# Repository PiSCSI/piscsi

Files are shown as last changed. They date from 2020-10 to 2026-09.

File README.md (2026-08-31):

# What is PiSCSI?









PiSCSI is a virtual SCSI device emulator that runs on a Raspberry Pi through the [PiSCSI hat](https://github.com/PiSCSI/piscsi/wiki/Hardware-Versions).
The software runs in userspace, and can emulate several SCSI devices at one time.
There is a control interface to attach / detach drives during runtime, as well as insert and eject removable media.

This project aims to be compliant with the SCSI specification and usable with any standards compliant SCSI controller (see [compatibility list](https://github.com/PiSCSI/piscsi/wiki/Compatibility)).
A handful of PiSCSI features were written specifically for vintage Macintosh and Atari computers and may depend on non-free device drivers on the host machine.

PiSCSI is a fork of [RaSCSI](https://github.com/RaSCSI/RaSCSI) and maintains compatibility with any RaSCSI hat.

Please check out the full story with much more detail on the [wiki](https://github.com/PiSCSI/piscsi/wiki)!

Browse the generated [PiSCSI command documentation](https://piscsi.github.io/piscsi/).

## How do I contribute?

PiSCSI is using a variant of the Gitflow Workflow. A quick overview:

- The *main* branch should always reflect the contents of the last stable release
- The *develop* branch should contain the latest tested & approved updates. Pull requests should be used to merge changes into develop.
- The rest of the feature branches are for developing new features
- A tag will be created for each "release". The releases will be named \<year\>.\<month\>.\<release number\> where the release number is incremented for each subsequent release tagged in the same calendar month. The first release of the month of January 2021 is called "21.01.01", the second one in the same month "21.01.02" and so on.

Note that the leading zeroes in the month and release number are used only in the git tags. The equivalent version number in the software is 21.1.1, 21.1.2, etc.

When you are ready to contribute code to PiSCSI, follow the [GitHub Forking and Pull Request workflow](https://docs.github.com/en/get-started/exploring-projects-on-github/contributing-to-a-project) to create your own fork where you can make changes, and then contribute it back to the project. Please remember to always make Pull Requests against the *develop* branch.

If you want to add a new translation, or improve upon an existing one, please follow the [Web Interface localization instructions](go/piscsi-web/README.md#updating-localizations). Once the translation is complete, please use the same workflow as above to contribute it to the project.

## GitHub Sponsors

Thank you to all of the GitHub sponsors who support the development community!

Extra special thank you to the Gold level sponsors!

- [@mikelord68](https://github.com/mikelord68)
- [@SamplerSpa-dev](https://github.com/SamplerSpa-de)

Special thank you to the Silver level sponsors!

- [@stinkerton18](https://github.com/stinkerton18)
- [@hsiboy](https://github.com/hsiboy)
- [@pendleton115](https://github.com/pendleton115)
- [@Teufelhunden-0311](https://github.com/Teufelhunden-0311)
- Private sponsor ;]

Thank you to Lin van der Slikke for the red panda logo design!

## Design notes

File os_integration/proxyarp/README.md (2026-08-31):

# PiSCSI NetworkManager profiles

PiSCSI supports two explicitly selected network-adapter topologies on Raspberry
Pi OS Trixie and Forky with NetworkManager. DaynaPort and Host Bridge use the
same host-side profiles. Installing the PiSCSI package only installs inert
templates, services, and `/etc/piscsi/network.conf`; it never creates a bridge,
changes an active connection, starts proxy-ARP, or changes firewall state.

The required `parprouted` and `dhcp-helper` packages are suggested rather than
installed automatically. This prevents `dhcp-helper`'s generic service from
binding DHCP on an existing host interface before the user selects proxy-ARP.

## Wired bridge

Bridge mode is the protocol-complete host-side choice: it supports DHCP,
AppleTalk, multicast, and non-IP Ethernet protocols. NetworkManager must own
the bridge, the physical Ethernet port, and the bridge address. PiSCSI owns
only the ephemeral `piscsi0` TAP membership while a network adapter is
attached. DaynaPort can use that complete Ethernet service; the Host Bridge
driver accepts only its own unicast frames and Ethernet broadcasts.

From a local console, preview and apply the named profile with:

```sh
sudo piscsi-network-profile --dry-run apply bridge eth0
sudo piscsi-network-profile --console-acknowledge apply bridge eth0
```

The command prints every change, refuses to run without NetworkManager, and
creates only the named `PiSCSI wired bridge` and `PiSCSI wired bridge port`
connections. `--console-acknowledge` is explicit approval and skips the
otherwise required local-terminal `APPLY` prompt. It can be removed with
`sudo piscsi-network-profile --console-acknowledge remove bridge`.

For manual configuration, the package provides inert keyfile templates in
`/usr/share/piscsi/network/`. Substitute unique UUIDs, the physical NIC, and
the physical Ethernet MAC in the templates, copy them to
`/etc/NetworkManager/system-connections/` with mode `0600`, then reload
NetworkManager. The bridge MAC must remain distinct from the emulated client
MAC on `piscsi0`. The equivalent commands are:

```sh
ethernet_mac=$(cat /sys/class/net/eth0/address)
nmcli connection add type bridge ifname piscsi_bridge con-name 'PiSCSI wired bridge' ipv4.method auto ipv6.method auto bridge.stp no 802-3-ethernet.cloned-mac-address "$ethernet_mac"
nmcli connection add type ethernet ifname eth0 master piscsi_bridge
nmcli connection up 'PiSCSI wired bridge'
```

Replace `eth0` with the selected physical Ethernet interface. Verify that the
bridge owns DHCP and the selected Ethernet MAC, and that the physical port has
no independent IP address before attaching a PiSCSI network adapter with
`mode=bridge:interface=piscsi_bridge`.

## Wi-Fi proxy ARP

Proxy-ARP exposes a PiSCSI network-adapter client directly on the Wi-Fi IPv4
LAN. It supports IPv4 unicast and DHCP only. It does not provide IPv6,
AppleTalk, multicast, mDNS reflection, or general Ethernet bridging. The Host
Bridge driver additionally accepts only its own unicast frames and Ethernet
broadcasts, regardless of the selected profile.

Before selecting this profile, remove any legacy PiSCSI NAT/firewall rules
manually. The package and profile command never remove, flush, or rewrite
iptables/nftables state. Keep a local console or another recovery path: Wi-Fi
proxy-ARP cannot replace a broken Wi-Fi association and is not a transparent
Ethernet bridge.

Install the suggested dependencies, then preview and apply the profile from a
local console:

```sh
sudo apt install parprouted dhcp-helper
sudo piscsi-network-profile --dry-run apply proxyarp wlan0
sudo piscsi-network-profile --console-acknowledge apply proxyarp wlan0
```

Replace `wlan0` with the NetworkManager-managed Wi-Fi interface holding the
Pi's global IPv4 lease. The command writes only
`/etc/piscsi/network.conf`, reloads PiSCSI runtime configuration, and disables
the generic `dhcp-helper.service` to avoid its UDP/67 conflict. To remove the
PiSCSI selection, use
`sudo piscsi-network-profile --console-acknowledge remove proxyarp`.
`PISCSI_PROXYARP_PROMISC=true` is a compatibility option; PiSCSI records and
restores the flag only if it enabled promiscuous mode itself.

The udev rule starts `piscsi-proxyarp.service` only after PiSCSI creates
`piscsi0`; it then starts the PiSCSI-owned DHCP relay. The relay conflicts with
the generic `dhcp-helper.service` to prevent UDP/67 contention. A NetworkManager
dispatcher restarts both PiSCSI services after the selected uplink reconnects
or receives a changed DHCP lease.

Verify an attachment with:

```sh
ip -br link show piscsi0
ip -4 addr show dev piscsi0
systemctl status piscsi-proxyarp piscsi-dhcp-relay
journalctl -u piscsi-proxyarp -u piscsi-dhcp-relay -b
```

On detach, PiSCSI removes only the exact `/32` it added to `piscsi0`, stops
only PiSCSI-owned processes, and restores promiscuous mode only when it had
changed it. It does not flush addresses, routes, or firewall state.

## Network-adapter attachment

Always submit a complete mode/interface pair. For example:

```sh
scsictl -i 6 -c attach -t scdp -f 'mode=bridge:interface=piscsi_bridge'
scsictl -i 6 -c attach -t scdp -f 'mode=proxyarp:interface=wlan0'
scsictl -i 5 -c attach -t scbr -f 'mode=bridge:interface=piscsi_bridge'
scsictl -i 5 -c attach -t scbr -f 'mode=proxyarp:interface=wlan0'
```

Do not use the retired `inet` parameter or a comma-separated interface list.
They describe the obsolete NAT/implicit-bridge path and are rejected.

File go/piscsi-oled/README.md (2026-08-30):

# PiSCSI OLED monitor

`piscsi-oled` is the standalone Go status monitor for 128×32 and 128×64
SSD1306 I2C displays. It shares the PiSCSI daemon client and protobuf bindings
with piscsi-web and piscsi-ctrlboard.

## I2C prerequisites

On Raspberry Pi OS, install supporting tools and enable I2C:

```sh
sudo apt-get update
sudo apt-get install --no-install-recommends --assume-yes \
  i2c-tools raspi-config
sudo raspi-config nonint do_i2c 0
```

Reboot if I2C was newly enabled. The display is normally available as
`/dev/i2c-1`; use `i2cdetect -y 1` to confirm the bus and its address (the
default is `0x3c`).

## Build and run

From the shared Go module root:

```sh
cd go
go build -o piscsi-oled ./cmd/piscsi-oled
./piscsi-oled --rotation=180 --height=64
```

Print the PiSCSI project version and copyright information without accessing
the display or daemon:

```sh
./piscsi-oled -v
```

The defaults preserve the previous monitor behavior: a 180-degree, 128×32
display at `/dev/i2c-1`, address `0x3c`, polling `localhost:6868` every 1000
milliseconds. Useful flags are:

- `--rotation=0|180`
- `--height=32|64`
- `--refresh_interval=1000`
- `--horizontal_scroll_step=6` (parameter pixels moved per screen refresh; `0` pauses scrolling). SCSI ID and device type remain fixed while the parameter field scrolls. Each scroll cycle holds its starting position for three frames, moves to the end, holds that final position for one additional frame, then restarts at the beginning.
- `--password=TOKEN`
- `--host=localhost` and `--port=6868`
- `--i2c-device=/dev/i2c-1` and `--i2c-address=0x3c`
- `--screensaver=off|ip|blank`
- `--screensaver-idle-timeout=5m` and `--screensaver-move-interval=30s`

### Screensavers

The optional `ip` screensaver keeps the network-status line visible but moves
it to a different text row periodically. The `blank` screensaver clears the
entire panel. Both activate only after the PiSCSI status has not changed for
the configured idle period; device, authentication, or network-status changes
immediately restore the normal display. Polling continues while a screensaver
is active.

```sh
./piscsi-oled --screensaver=ip --screensaver-idle-timeout=5m \
  --screensaver-move-interval=30s

./piscsi-oled --screensaver=blank --screensaver-idle-timeout=5m
```

The default `--screensaver=off` preserves existing behavior. The duration flags
accept Go durations such as `30s`, `5m`, and `1h`.

Run a physical-display diagnostic without connecting to the PiSCSI daemon:

```sh
./piscsi-oled --height=32 --rotation=180 --diagnostic
```

It shows the embedded startup and shutdown splash screens, clears the panel,
and exits. Test this on both display heights and rotations after installing the
binary; standard CI cannot exercise I2C hardware.

## Service

The `piscsi-oled` Debian package installs and manages the
[`piscsi-oled.service`](../../os_integration/systemd/piscsi-oled.service)
unit. It runs with a dynamic unprivileged user and the `i2c` supplementary
group; ensure the I2C device grants group access. On `SIGINT` or `SIGTERM`,
the monitor shows the shutdown splash, blanks the panel after 700 ms, and
exits.

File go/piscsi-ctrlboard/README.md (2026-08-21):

# PiSCSI Control Board client

`piscsi-ctrlboard` is the Go client for the PiSCSI Control Board. It reads the
rotary encoder and buttons through the PCA9554 I2C expander, presents the menu
on a 128x64 SSD1306 I2C display, and sends PiSCSI daemon commands for SCSI-ID
management, image attach/eject, profiles, and system actions. The input path
is kept separate from menu, network, and display work so that hardware events
remain responsive.

It is intended to run on a Raspberry Pi with the Control Board attached. By
default it uses `/dev/i2c-1`, PCA9554 address `0x3f`, SSD1306 address `0x3c`,
and BCM GPIO 9 for the expander interrupt. The PiSCSI daemon is expected at
`localhost:6868`.

The PiSCSI Control Board hardware and original Python client were created by
Benjamin Zeiss, and the Go client is a rewrite of that software.

## I2C and GPIO prerequisites

Enable I2C on Raspberry Pi OS and verify that the board devices are visible:

```sh
sudo apt-get update
sudo apt-get install --no-install-recommends --assume-yes i2c-tools raspi-config
sudo raspi-config nonint do_i2c 0
i2cdetect -y 1
```

Reboot if I2C was newly enabled. The usual addresses are `0x3c` for the
display and `0x3f` for the PCA9554. The process also needs access to
`/dev/gpiochip0`; run it with the appropriate device permissions or through
the service manager.

## Build and run

From the shared Go module root, build the native binary and run it on the Pi:

```sh
cd go
go build -o piscsi-ctrlboard ./cmd/piscsi-ctrlboard
./piscsi-ctrlboard
```

Print the PiSCSI project version and copyright information without accessing
the Control Board hardware or daemon:

```sh
./piscsi-ctrlboard -v
```

The Makefile offers equivalent build targets, including cross-compilation for
Raspberry Pi targets:

```sh
cd go
make build-ctrlboard
make build-ctrlboard-linux-arm64
make build-ctrlboard-linux-armv7
```

Use `--help` to list all options. Common overrides include `--host` and
`--port` for the daemon, `--password` for a daemon token, `--rotation=180` for
an inverted display, and `--transitions` to animate submenu navigation. Set
`--display=false` to disable SSD1306 rendering; the Control Board PCA9554 and
GPIO interrupt are still required.

```sh
./piscsi-ctrlboard --host=piscsi.local --port=6868 --rotation=180
./piscsi-ctrlboard --diagnostic
```

Diagnostic mode logs PCA9554 snapshots, decoded input events, queue drops, and
latency counters. It is useful when verifying encoder direction, button
debounce, I2C addresses, or the GPIO interrupt connection.

## Service

The `piscsi-ctrlboard` Debian package installs
[`piscsi-ctrlboard.service`](../../os_integration/systemd/piscsi-ctrlboard.service).
Enable it after installing the package:

```sh
sudo systemctl enable --now piscsi-ctrlboard
```

Use a systemd drop-in to pass non-default hardware addresses, daemon
connection details, or display options.

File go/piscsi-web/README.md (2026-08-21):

# PiSCSI Web Interface (Go)

Go implementation of the PiSCSI web interface, providing a browser-based control panel for the PiSCSI SCSI emulator.

## Components

### Web Interface (`piscsi-web`)

HTTP server providing:

- Immediate access without a login page
- Device management (attach/detach SCSI devices)
- File operations (upload/download/manage disk images)
- System administration
- Server-rendered HTML forms

**Architecture:**

- **Form-post centric**: POST-Redirect-GET pattern with flash messages
- **Minimal JavaScript**: Designed for retro computers (only confirmations/prompts)
- **Template-driven**: Server-side HTML rendering via Go templates

The web interface does not expose a general-purpose JSON API and does not
preserve the former Python web client's `Accept: application/json` response
contract. Form and page routes always use HTML responses or redirects. The
`/healthcheck` endpoint deliberately returns a small JSON response for service
monitoring; downloads and static resources use their corresponding media
types. Any future automation API should be introduced as a separately
documented and versioned interface.

### Mock PiSCSI Daemon (`mock-piscsi`)

Minimal gRPC server simulating the PiSCSI daemon for development/testing without hardware.

## Building

### Baseline Build Environment

For normal PiSCSI installations, use a published PiSCSI binary; Go is needed
only when building from source.

The source build is distribution-independent. It requires:

- Go 1.25 or newer, or Go 1.21 or newer as a bootstrap toolchain
- Git, Make, CA certificates, and OpenSSL
- Network access to download Go modules, unless the module cache is already
  populated

The module requires Go 1.25 and selects a patched Go release with the
`toolchain` directive in `go.mod`. An operating system whose packaged Go
version is older than 1.25 can use Go's automatic toolchain selection instead
of replacing its system compiler. This applies to any distribution with Go
1.21 through 1.24, including Raspberry Pi OS based on Debian Trixie with its
Go 1.24 package.

Go versions older than 1.21 cannot perform automatic toolchain selection.
On such systems, install a current Go toolchain directly, use the release
container, or install a published PiSCSI binary.

The build generates Go bindings from the canonical schema in
`../../proto/piscsi_interface.proto`. It requires the Protocol Buffers compiler
and the Go protobuf generator.

On Debian-family systems, install the bootstrap compiler and native build
dependencies with:

```shell
sudo apt-get update
sudo apt-get install --yes ca-certificates git golang-go make openssl protobuf-compiler
go install google.golang.org/protobuf/cmd/protoc-gen-go@v1.36.11
export PATH="$(go env GOPATH)/bin:$PATH"
```

Install the equivalent packages through the system package manager on other
operating systems.

### Build Commands

**Web interface:**

From `go/piscsi-web`, select the toolchain, verify the source, and build the
application with:

```shell
GOTOOLCHAIN=auto go version
GOTOOLCHAIN=auto go mod download
make test
go vet -tags nomsgpack ./...
make build
```

`make test` is portable to 32-bit ARM and Raspberry Pi kernels that cannot run
Go's race detector. On a supported development host, run `make test-race` to
include race detection.

Run these commands from the module directory so the `go` command sees the
version requirements in `go.mod`. Confirm that the first command reports the
patched toolchain selected by `go.mod`, rather than an older bootstrap
toolchain or an unpatched Go 1.25.0 toolchain.

Automatic toolchain selection requires network access to a Go module proxy and
the checksum database. For a reproducible or offline package build, install the
exact Go toolchain version used by CI in advance, or build in the release
container. Keep the `toolchain` directive in `go.mod` synchronized with
`GO_VERSION` in `.github/workflows/go-web.yml`.

PiSCSI does not expose Gin's optional MessagePack binding or renderer. Supported
builds therefore use Gin's `nomsgpack` build tag, which avoids compiling the
memory-intensive `ugorji/codec` dependency. This is especially important when
building natively on a Raspberry Pi 3.

On a low-memory system, also limit Go to one package build at a time:

```shell
make build GOBUILD='go build -p=1'
```

If native tests also encounter memory pressure, use the same setting:

```shell
make test GOTEST='go test -p=1'
```

Static builds are also available:

```shell
make build-linux-arm64-static
make build-linux-armv7-static
```

**Mock daemon:**

```shell
make mock
```

**Regenerate protobuf bindings:**

```shell
make proto
```

### Custom build-time data-directory defaults

The `BASE_DIR`, `SHARED_DIR`, `CONFIG_DIR`, `DRIVER_DIR`, and
`DRIVE_PROPERTIES_FILE` environment
variables override the application's defaults at runtime.
When building a binary for a legacy installation where data dirs are under `/home/pi`,
the fallback defaults can instead be selected with Makefile variables:

```shell
make build \
  DEFAULT_BASE_DIR=/home/pi/images \
  DEFAULT_SHARED_DIR=/home/pi/shared \
  DEFAULT_CONFIG_DIR=/home/pi/.config/piscsi \
  DEFAULT_DATA_DIR=/home/pi \
  DEFAULT_DRIVE_PROPERTIES_FILE=/home/pi/drive_properties.json \
  DEFAULT_SESSION_KEY_FILE=/home/pi/.config/piscsi/session.key
```

The resulting binary uses these directories only when the corresponding
environment variable is unset. `DEFAULT_SESSION_KEY_FILE` is used only when
`SESSION_KEY_FILE` is unset. `DEFAULT_DRIVE_PROPERTIES_FILE` is used only when
`DRIVE_PROPERTIES_FILE` is unset. `DEFAULT_DATA_DIR` sets the support-data root;
the default driver directory is its `mac-hard-disk-drivers` subdirectory.

The packaged installation stores root-owned, read-only support data below
`/var/lib/piscsi/data`. The Macintosh driver images occupy its
`mac-hard-disk-drivers` subdirectory, leaving the parent directory available
for future PiSCSI support data.

## Installing

Run the installer from `go/piscsi-web` after building the application. On
x86_64, the native build name can be installed directly:

```shell
make build
sudo make install
```

On Raspberry Pi, name the binary for the target architecture because the
installer uses the architecture suffix to select it:

```shell
# 64-bit Raspberry Pi OS (ARM64)
make build-linux-arm64
sudo make install
```

```shell
# 32-bit Raspberry Pi OS (ARMv7)
make build-linux-armv7
sudo make install
```

The installer copies the selected web binary and assets to `/opt/piscsi/web`,
installs the systemd unit, creates the service account and data directories,
creates an empty default environment file, provisions the browser-session key,
and enables the web service.

### Optional Macintosh driver injection

Macintosh driver injection when creating HFS images is optional. The installer
does not provide driver images. Place regular `.bin` or `.img` driver files in
the default driver directory; the web interface lists them as HFS formatting
options:

```shell
sudo install -d -o root -g root -m 0755 /var/lib/piscsi/data/mac-hard-disk-drivers
sudo install -o root -g root -m 0644 /path/to/driver.bin /path/to/driver.img \
  /var/lib/piscsi/data/mac-hard-disk-drivers/
```

Files whose names start with `miniscsi` are created with an `Apple_Driver43`
partition and MiniSCSI-specific boot metadata. Other driver files use the legacy
16 KiB `Apple_Driver` format.

Alternatively, set `DRIVER_DIR` to an existing, readable directory containing
those files. Without the driver images, the web service remains available but
the corresponding image-format options cannot be used.

Archive inspection and extraction use the `lsar` and `unar` commands from the
Debian `unar` package. `easyinstall.sh` installs this package automatically.
For a standalone Go installation, install it before starting the service:

```shell
sudo apt-get install --yes unar
```

Verify the installation with:

```shell
sudo systemctl status piscsi-web
sudo journalctl -u piscsi-web -f
```

### Migrating from the Python web interface

The Python web interface stored disk images in `~/images`, shared files in
`~/shared_files`, and saved configurations and image-property files in
`~/.config/piscsi`. After installing the Go web interface, stop the web
service and run:

```shell
sudo systemctl stop piscsi-web
sudo make migrate-data
sudo systemctl start piscsi-web
```

The migration copies these files to the default directories under
`/var/lib/piscsi`, applies the ownership and permissions required by the
`piscsi-web` service, and imports a legacy backend authentication token into
the protected `/etc/piscsi-web/piscsi-web.env` file. Existing destination
files are preserved, and the source files are not removed. It also copies
existing Macintosh driver images from `~/mac-hard-disk-drivers` to
`/var/lib/piscsi/data/mac-hard-disk-drivers`. Use
`./scripts/migrate-data.sh --dry-run` to preview the migration or
`--source-home PATH` when the legacy installation did not use `/home/pi`.

Legacy RaSCSI 21.10 configuration files with a JSON list at the top level
cannot be converted by the migration script. Load and re-save them with the
Python web interface before switching. Current object-format JSON files retain
their schema, with absolute paths under the legacy image directory converted
to portable relative image paths.

## Running

### Development Mode

```shell
# Terminal 1: Start mock daemon
./mock-piscsi

# Terminal 2: Start web interface
SESSION_KEY="$(openssl rand -base64 32)" \
BASE_DIR=/absolute/path/to/images \
SHARED_DIR=/absolute/path/to/shared \
CONFIG_DIR=/absolute/path/to/config \
DRIVER_DIR=/absolute/path/to/mac-hard-disk-drivers \
./piscsi-web
```

Access at: <http://localhost:8080>

Create the configured data directories before starting the process. Direct
`SESSION_KEY` use is development-only and creates a new session identity each
time the example is run. To preserve development sessions across restarts,
write `openssl rand -base64 32` to a mode `0600` file once and configure its
absolute path through `SESSION_KEY_FILE`.

### Saved configurations

The Go web interface uses the current object-format JSON configuration with
`version`, `devices`, and `reserved_ids` fields. Reservation memos are not
supported; a `memo` field in an existing object-format file is ignored.
When `default.json` is present in the configured configuration directory, it
is validated and loaded automatically during web-server startup.

The obsolete RaSCSI 21.10 format, which uses a device list at the top level, is
not supported. To migrate one of these files, load it with the Python web
client and save it again. The resulting object-format file can then be loaded
by the Go web interface.

### Production Mode

On a packaged installation, start the web interface through systemd:

```shell
sudo systemctl start piscsi-web
sudo systemctl status piscsi-web
```

The packaged web service runs as the dedicated `piscsi-web` system user with
the `piscsi` group. The interface is usable immediately after loading and does
not authenticate browser users. Keep it restricted to a trusted network.

Do not run `/opt/piscsi/web/piscsi-web` directly as a regular user: the
production session master key is deliberately readable only by root and the
`piscsi` service group.

For development or a manually launched private instance, use a separate
session key and user-writable data directories rather than changing the
permissions of the production key.

Default configuration:

- Server: `0.0.0.0:8080`
- PiSCSI daemon: `localhost:6868`
- Disk images: `/var/lib/piscsi/images`
- Shared files: `/var/lib/piscsi/shared`
- Saved configuration: `/var/lib/piscsi/config`
- Macintosh hard disk drivers: `/var/lib/piscsi/data/mac-hard-disk-drivers`
- Session master key: `/etc/piscsi-web/session.key`
- Protected configuration: `/etc/piscsi-web/piscsi-web.env`

### System Data Permissions

The packaged services are expected to use the following ownership and
permission modes. The optional support-data rows apply only when Macintosh
driver injection has been configured:

| Path | Owner and group | Mode |
| --- | --- | --- |
| `/var/lib/piscsi` | `root:piscsi` | `2770` |
| `/var/lib/piscsi/images` | `root:piscsi` | `2770` |
| `/var/lib/piscsi/shared` | `root:piscsi` | `2770` |
| `/var/lib/piscsi/config` | `piscsi-web:piscsi` | `2770` |
| `/var/lib/piscsi/data` | `root:root` | `0755` |
| `/var/lib/piscsi/data/mac-hard-disk-drivers` | `root:root` | `0755` |
| `/var/lib/piscsi-web` | `piscsi-web:piscsi` | `0700` |
| `/etc/piscsi-web` | `root:piscsi` | `0750` |
| `/etc/piscsi-web/piscsi-web.env` | `root:piscsi` | `0640` |
| `/etc/piscsi-web/session.key` | `root:piscsi` | `0640` |

Mode `2770` sets the setgid bit on shared directories so newly created files
inherit the `piscsi` group. Both services use `UMask=0007`. The configuration
directory and session key permissions must not be relaxed merely to let regular
users launch the production service manually.

### Session-key provisioning and rotation

The installer preserves a valid `/etc/piscsi-web/session.key` byte-for-byte on
upgrade. It generates a new key only when that file does not exist. A malformed
or short existing key stops the installation instead of replacing it.

The new file contains standard base64 that decodes to at least 32 random bytes.
The application derives separate cookie-authentication and cookie-encryption
keys using HKDF-SHA-256; the master key itself is never logged. The cookie
stores per-browser language and theme preferences plus short-lived flash
messages. Signing prevents client-side tampering, while encryption avoids
exposing operational messages and paths to the browser.

Rotate the production key only as a deliberate maintenance action:

```shell
sudo systemctl stop piscsi-web
umask 077
SESSION_KEY_TMP=$(mktemp)
openssl rand -base64 32 > "$SESSION_KEY_TMP"
sudo install -o root -g piscsi -m 0640 \
  "$SESSION_KEY_TMP" /etc/piscsi-web/session.key
rm -f "$SESSION_KEY_TMP"
sudo systemctl start piscsi-web
```

Rotation immediately invalidates every existing browser preference and pending
flash message. Keep a protected backup of the previous key until the restart is
verified if rollback must preserve these cookies.

## Configuration

Environment variables:

- `PISCSI_HOST`: PiSCSI daemon host (default: `localhost`)
- `PISCSI_PORT`: PiSCSI daemon port (default: `6868`)
- `PISCSI_TOKEN`: Token password for an authenticated PiSCSI daemon; the
  equivalent `--password` command-line option overrides it when non-empty
- `SERVER_HOST`: Web server listen host (default: `0.0.0.0`)
- `SERVER_PORT`: Web server port (default: `8080`)
- `BASE_DIR`: Disk image directory (default: `/var/lib/piscsi/images`)
- `SHARED_DIR`: Shared-file directory (default: `/var/lib/piscsi/shared`)
- `CONFIG_DIR`: Saved configuration directory (default: `/var/lib/piscsi/config`)
- `DRIVER_DIR`: Lido and SpeedTools driver-image directory (default:
  `/var/lib/piscsi/data/mac-hard-disk-drivers`)
- `DRIVE_PROPERTIES_FILE`: Drive property presets (default:
  `drive_properties.json`; Debian package: `/etc/piscsi-web/drive_properties.json`)
- `TEMPLATES_DIR`: HTML template directory used only as a development fallback
  (default: `web/templates`; the release binary embeds templates)
- `STATIC_DIR`: Static-asset directory used only as a development fallback
  (default: `web/static`; the release binary embeds static assets)
- `MAX_FILE_SIZE`: Maximum upload size in bytes (default: `4294967296`; maximum:
  `146789695488`, the largest supported drive preset)
- `SESSION_MAX_AGE`: Session lifetime in seconds (default: `86400`)
- `SESSION_KEY_FILE`: Protected base64 master-key file (default:
  `/etc/piscsi-web/session.key`)
- `SESSION_KEY`: Development-only base64 master key used only when
  `SESSION_KEY_FILE` is not configured

`SESSION_KEY_FILE` takes precedence when both secret settings are present,
including when the file setting is explicitly empty or invalid. Production
deployments must use the file. All configured numbers, hosts, paths, and
required directory access are validated before the server is constructed;
malformed values never fall back to defaults.

Startup fails if the session key is missing, malformed, too short, group-writable, or
accessible by other users, if a required directory is unusable, or if the
PiSCSI daemon requires a missing or invalid token.

Because there is no browser authentication, public-internet exposure is
unsupported. Keep the service on a trusted LAN.

## Updating Localizations

The gettext catalogs are stored as uncompiled PO files under
`web/translations/<locale>/LC_MESSAGES/messages.po` and are embedded directly
in the binary. Install GNU gettext (`gettext` on Debian and Homebrew) before
maintaining them.

The Go renderer looks up the final English text produced by the templates and
handlers. From `go/piscsi-web`, extract these messages, regenerate
`messages.pot`, merge the template into every PO file, and validate the
results with:

```shell
./scripts/update-translations.sh
```

The script stages and validates the generated POT and every merged PO file
before replacing any source file. Existing translations are retained when
their message IDs still match. Review new, fuzzy, and obsolete entries after
running it, update their translations, and run the script again before
committing `messages.pot` and the PO files.

## Project Structure

```shell
.
├── cmd/
│   ├── piscsi-web/       # Web server entrypoint
│   └── mock-piscsi/      # Mock daemon entrypoint
├── internal/
│   ├── server/         # HTTP handlers, routing, flash messages
│   ├── piscsi/         # gRPC client for PiSCSI daemon
│   ├── config/         # Configuration management
│   └── driveprops/     # Drive properties database
├── web/
│   ├── templates/      # HTML templates
│   └── static/         # CSS, JS, images
├── drive_properties.json
└── mock-piscsi         # Built mock daemon
```

## Development Notes

- Templates are embedded in the binary via `embed` directives
- Session storage uses gorilla/sessions with cookie-based persistence
- Flash messages require `gob.Register()` for serialization
- `../../proto/piscsi_interface.proto` is the canonical protocol definition.
- Go bindings are generated automatically by Make targets and are not committed.

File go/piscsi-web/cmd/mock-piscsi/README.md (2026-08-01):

# Mock PiSCSI Daemon

A lightweight mock implementation of the PiSCSI daemon for testing the web frontend without physical hardware.

## Quick Start

Build and run the mock daemon:

```shell
# Build the mock daemon
make mock

# Run it (listens on port 6868)
./mock-piscsi
```

In another terminal, start the web interface:

```shell
DISABLE_PAM=true FALLBACK_USER=test FALLBACK_PASSWORD=test ./piscsi-web
```

Then open <http://localhost:8080> in your browser.

## Features

The mock daemon responds to all major PiSCSI operations:

- **VERSION_INFO** - Returns mock version information
- **SERVER_INFO** - Returns full server configuration
- **DEVICES_INFO** - Lists attached devices (initially one mock drive)
- **DEFAULT_IMAGE_FILES_INFO** - Lists available disk images
- **DEVICE_TYPES_INFO** - Returns supported device types
- **LOG_LEVEL_INFO** - Returns log level information
- **NETWORK_INTERFACES_INFO** - Returns network interfaces
- **ATTACH** - Simulates attaching a device
- **DETACH/DETACH_ALL** - Simulates detaching devices

## Customizing Mock Data

All mock responses are generated by functions in `main.go`. To customize:

### Add More Mock Images

Edit `getMockImageFilesInfo()`:

```go
ImageFiles: []*pb.PbImageFile{
    {
        Name:     "my-custom-disk.hda",
        Type:     pb.PbDeviceType_SCHD,
        Size:     21474836480, // 20GB
        ReadOnly: false,
    },
    // Add more images here...
}
```

### Add Mock Attached Devices

Edit `getMockDevicesInfo()`:

```go
Devices: []*pb.PbDevice{
    {
        Id:         1,
        Unit:       0,
        Type:       pb.PbDeviceType_SCCD,  // CD-ROM
        Status:     "ready",
        File:       "system-cd.iso",
        Vendor:     "PiSCSI",
        Product:    "CD-ROM",
        Revision:   "1.0",
        BlockSize:  2048,
        BlockCount: 300000,
    },
    // Add more devices here...
}
```

### Change Version Info

Edit `getMockVersionInfo()`:

```go
return &pb.PbVersionInfo{
    MajorVersion: 25,
    MinorVersion: 0,
    PatchVersion: 1,
    Suffix:       "-custom",
}
```

## Protocol Details

The mock daemon implements the PiSCSI protobuf protocol:

1. Client sends: `RASCSI` (6 bytes) + size (4 bytes, LE) + protobuf message
2. Server responds: size (4 bytes, LE) + protobuf message

All operations are logged to stdout for debugging.

## Tips

- Run with `2>&1 | tee mock.log` to save logs
- The mock daemon doesn't validate requests - it always returns success
- Restart the daemon to reset all state
- You can run multiple instances on different ports by modifying the `Port` constant

## Troubleshooting

**Port already in use:**

```shell
# Find what's using port 6868
lsof -i :6868

# Or kill all piscsi processes
pkill piscsi
pkill mock-piscsi
```

**Web interface can't connect:**

- Make sure the mock daemon is running first
- Check the daemon logs for incoming connections
- Verify the web interface is configured for localhost:6868 (default)

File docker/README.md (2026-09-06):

# Docker Environment for Development and Testing

⚠️ **Important:** The Docker environment is unable to connect to the PiSCSI board and is
intended for development and testing purposes only. To setup PiSCSI on a Raspberry Pi
refer to the [setup instructions](https://github.com/PiSCSI/piscsi/wiki/Setup-Instructions)
on the wiki instead.

## Introduction

This documentation covers developing and testing the Go web UI.

Additions, amendments and contributions for additional workflows are most welcome.

## Getting Started

The easiest way to launch a new environment is to use Docker Compose.

```sh
cd docker
docker compose up
```

Containers will be built and started for the PiSCSI server and the web UI.

The web UI can be accessed at:

* http://localhost:8080

To stop the containers, press *Ctrl + C*, or run `docker compose stop` 
from another terminal.

## Environment Variables

The following environment variables are available when using Docker Compose:

| Environment Variable | Default  |
| --- |---|
| `OS_VERSION` | trixie |
| `WEB_HTTP_PORT` | 8080 |
| `BACKEND_HOST` | backend  |
| `BACKEND_PORT` | 6868 |
| `BACKEND_PASSWORD` | *[None]* |
| `BACKEND_LOG_LEVEL`  | debug |
| `PISCSI_DOCKER_UID`  | 1000 |
| `PISCSI_DOCKER_GID`  | 1000 |

**Examples:**

Run Debian "trixie":

```sh
OS_VERSION=trixie docker compose up
```

The Docker entrypoint generates an ephemeral session key for local development.
Set `SESSION_KEY` yourself if browser sessions must survive a container restart.

Run the Go web-client test suite with:

```sh
docker compose --profile webui-tests run --rm go-test
```

## Volumes

When using Docker Compose the following volumes will be mounted automatically:

| Local Path | Container Path |
| --- | --- |
| docker/volumes/images/  | /var/lib/piscsi/images/  |
| docker/volumes/config/  | /var/lib/piscsi/config/  |

## How To

### Rebuild Containers

You should rebuild the container images after checking out a different version of
PiSCSI or making changes to the Go web client or its runtime dependencies.

```sh
docker compose up --build
```

### Open a Shell on a Running Container

Run the following command, replacing `[CONTAINER]` with `backend` or `web`.

```sh
docker compose exec [CONTAINER] bash
```

### Setup Live Editing for the Web UI

Use a `docker-compose.override.yml` to mount the local `go` directory into the
build workspace used by the `go-test` service.

The web binary embeds templates and static assets, so rebuild and restart the
`web` service after editing Go web-client files.

**Example:**

```yaml
services:
  go-test:
    volumes:
      - ../go:/src/go:delegated
```

### Connect the Web UI to a Real PiSCSI

This can be useful for testing, but there are some caveats, e.g. the PiSCSI and the
web UI will be accessing separate `images` directories.

```sh
BACKEND_HOST=foo BACKEND_PASSWORD=bar docker compose up
```

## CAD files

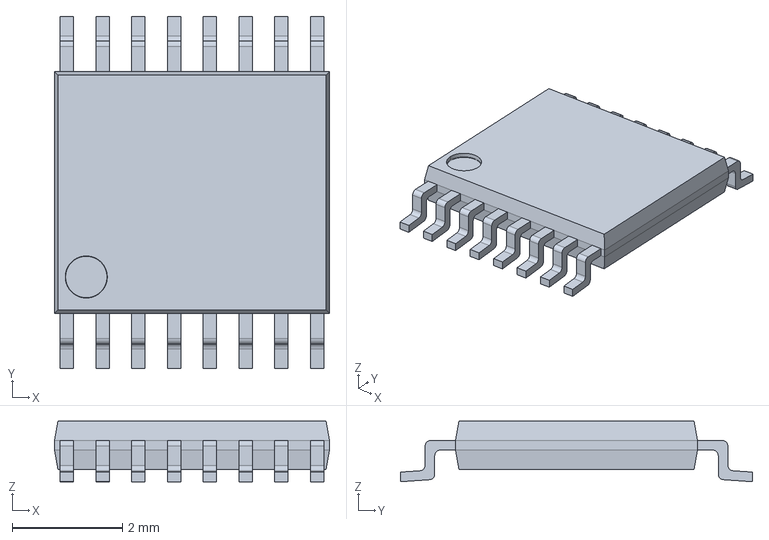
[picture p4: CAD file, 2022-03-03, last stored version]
hw/ctrl_board_v1p5/PCA9554APW_118/PCA9554APW_118.step
5.00 x 6.41 x 1.10 mm

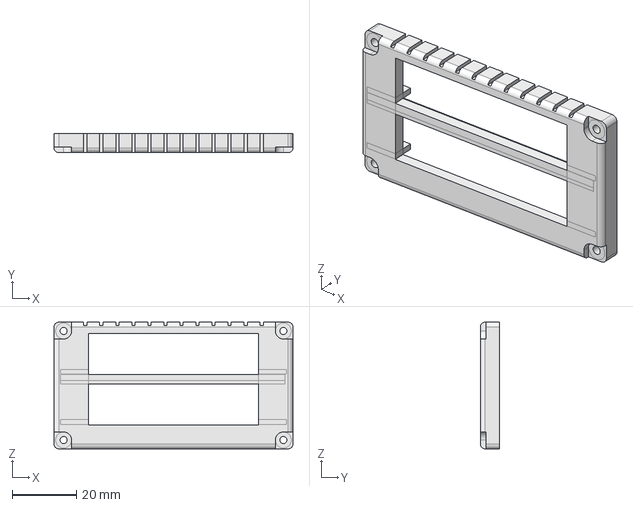
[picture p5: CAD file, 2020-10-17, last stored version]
hw/IIciCase/IIciCase.FCStd
74.5 x 6.00 x 39.5 mm

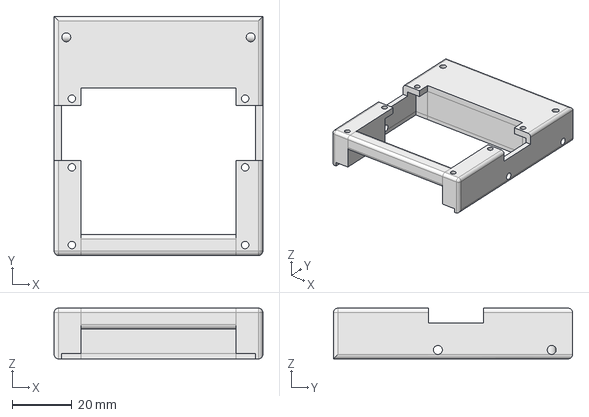
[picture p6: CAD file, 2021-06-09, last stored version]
hw/pb_bracket/powerbook_bracket.step
69.8 x 80.0 x 17.0 mm

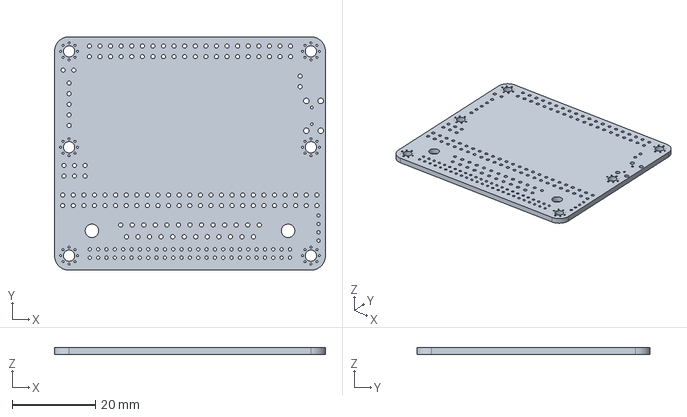
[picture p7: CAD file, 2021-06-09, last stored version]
hw/rascsi_2p4/rascsi_2p4.step
65.0 x 56.0 x 1.60 mm

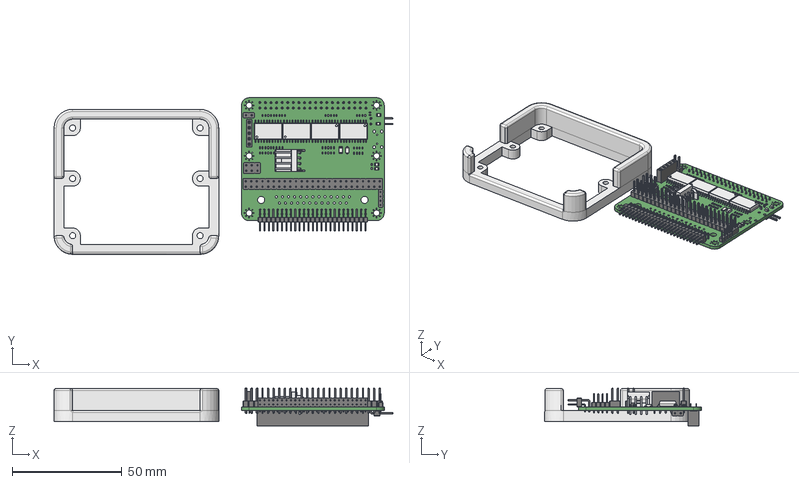
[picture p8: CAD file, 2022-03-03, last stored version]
hw/rascsi_pogo_holder/rascsi_pogo_holder.FCStd
154.3 x 71.3 x 17.2 mm
RaSCSI Holder

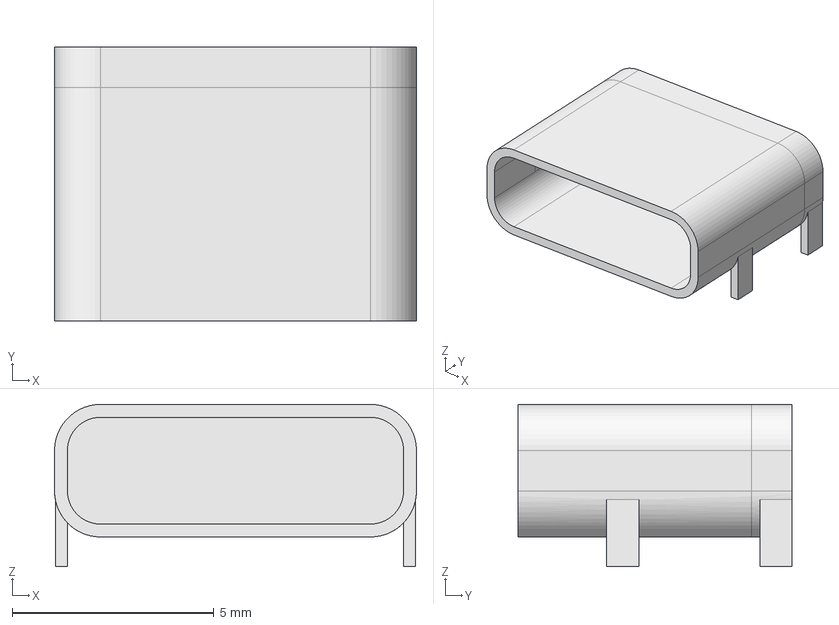
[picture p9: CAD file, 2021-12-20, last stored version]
hw/rascsi_zero_1p0/TYPE-C-31-M-17/type-c-31-m-17-Body.step
8.98 x 6.80 x 4.03 mm

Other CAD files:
hw/rascsi_2p5/rascsi_2p5.step
hw/rascsi_zero_1p0/TYPE-C-31-M-17/type-c-31-m-17.FCStd
hw/pb_bracket/powerbook_bracket.FCStd
hw/pb_bracket/powerbook_bracket.stl
hw/rascsi_pogo_holder/rascsi_pogo_holder.stl

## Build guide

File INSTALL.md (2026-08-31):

# Installing PiSCSI

The recommended way to install PiSCSI is via the binary deb packages.
Find the latest release on the [GitHub releases page](https://github.com/PiSCSI/piscsi/releases) and download the `piscsi_*.deb` file for your Raspberry Pi architecture.

If you want the Web interface, download the `piscsi-web_*.deb` file as well.
If your Raspberry Pi has an OLED screen, download the `piscsi-oled_*.deb` file, and if you have a PiSCSI Control Board, download the `piscsi-ctrlboard_*.deb` file.

## Runtime dependencies

Use apt to install the packages and their dependencies, for example the mandatory runtime dependencies for the _piscsi_ daemon:

```sh
sudo apt update
sudo apt install libprotobuf-dev libspdlog-dev libpcap-dev
```

The _piscsi_ daemon requires the following packages to be installed on the system:

- `libprotobuf-dev` for the protobuf runtime library
- `libspdlog-dev` for the spdlog runtime library
- `libpcap-dev` for the pcap runtime library

Note that the _-dev_ packages are not strictly required at runtime, but they are the easiest way to install the libraries on Debian-based systems, since
they are named consistently regardless of the Raspberry Pi architecture. The _-dev_ packages are also required to build PiSCSI from source.

In addition, these optional packages enables additional functionality:

- `dhcp-helper` for proxy ARP support
- `parprouted` for proxy ARP support
- `rsyslog` for logging

The _piscsi-web_ package has the following optional runtime dependencies:

- `genisoimage` for creating ISO images
- `unar` for extracting compressed archives
- `dosfstools` for creating FAT filesystems
- `hfdisk` for creating HFS partition tables
- `hfsutils` for creating HFS filesystems
- `groff` for displaying man pages
- `man2html` for converting man pages to HTML
- `disktype` for identifying disk image types

The _piscsi-oled_ and _piscsi-ctrlboard_ packages have the following optional runtime dependency:

- `i2c-tools` for configuring and testing I2C devices

## Installing the packages

Use `dpkg` to install the downloaded packages. For example, if you downloaded the `piscsi_*.deb` and `piscsi-web_*.deb` files to your home directory:

```sh
sudo dpkg -i ~/piscsi_*.deb ~/piscsi-web_*.deb
```

In most cases, dpkg will report missing dependencies. Use `apt` to install them.

## Build from source

This guide builds the C++ PiSCSI daemon and command-line tools from a source checkout.
Note that building the C++ code directly on Raspberry Pi hardware can be very slow.
Cross-compiling on a more powerful host is recommended.

Building from source is most useful for development, testing,
or trying an unreleased change. PiSCSI is developed and tested primarily on
recent Raspberry Pi OS releases.

The C++ code and tests can be built on most Unix-like systems,
but the GPIO hardware interface is only available on a Raspberry Pi with a
PiSCSI hat.

## Build prerequisites

On Raspberry Pi OS, install the PiSCSI C++ build dependencies with:

```sh
sudo apt update
sudo apt install --yes \
  build-essential ca-certificates git protobuf-compiler rsyslog \
  clang libgmock-dev libpcap-dev libprotobuf-dev libspdlog-dev
```

`libgmock-dev` supplies the unit-test dependency. You may omit it when you do
not intend to build or run tests.

For the Meson build system, also install Meson and Ninja:

```sh
sudo apt install --yes meson ninja-build
```

Clone the repository:

```sh
git clone https://github.com/PiSCSI/piscsi.git
cd piscsi
```

The web interface and the optional OLED/control-board programs are built with
Go. Start with the [web interface README](go/piscsi-web/README.md); the OLED
and control-board directories each have their own README as well.

## Build with Meson

Meson is configured from the repository root. A separate build directory keeps
generated files out of the checkout.

```sh
meson setup build
meson compile -C build
```

The default target set builds `piscsi`, `scsictl`, `scsimon`, `scsiloop`,
`scsidump`, and the unit tests. `scsiloop` requires Linux on Raspberry Pi GPIO
hardware.

To select targets explicitly, pass a Meson array option:

```sh
meson setup build -Dtarget=piscsi,scsictl
meson compile -C build
```

Run unit tests when the Google Test/Mock packages are installed:

```sh
meson test -C build
```

Install the Meson-built binaries and installed data with:

```sh
sudo meson install -C build
```

By default this installs executable and manual-page files under `/usr/local`,
along with the other data declared by the Meson project. Use `--prefix` to
change the installation root. You may need to manually adjust the systemd
unit files to match the prefix.

## Build with Make

The legacy Makefile is run from `cpp/`. It compiles C++ sources there and
writes binaries to `cpp/bin/`.

```sh
cd cpp
make -j"$(nproc)" all
```

For a development build with debug symbols and no optimization:

```sh
make -j"$(nproc)" DEBUG=1 all
```

Run the C++ unit tests:

```sh
make -j"$(nproc)" test
```

The Makefile accepts `CROSS_COMPILE`, for example `CROSS_COMPILE=arm-linux-gnueabihf-`, and
`DEFAULT_IMAGE_FOLDER` to change the compiled default image directory.

Install the Make-built development files with:

```sh
sudo make install
```

After a Makefile installation, reload logging and enable/start the service as
needed:

```sh
sudo systemctl restart rsyslog
sudo systemctl enable --now piscsi
sudo systemctl status piscsi
```

The daemon log is written to `/var/log/piscsi.log` when the supplied rsyslog
configuration is active.

## Cleaning and rebuilding

For a clean Makefile build:

```sh
cd cpp
make clean
```

For Meson, remove the build directory and configure it again:

```sh
rm -rf build
meson setup build
```

The two build systems can be used in parallel, but they do not share build artifacts.

For system setup and SCSI hardware guidance, see the
[PiSCSI Setup Instructions](https://github.com/PiSCSI/piscsi/wiki/Setup-Instructions).

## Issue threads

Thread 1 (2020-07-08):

CD-ROM Emulation doesn't work with stock Apple drivers

akuker, 2020-07-08:
The "stock" version of Apple's CD-ROM driver for MacOS 8.x (and probably all versions of "classic" Mac OSs) does not recognize the emulated CD-ROM of RaSCSI. At startup, the CD-ROM driver will send an unsupported command that is not supported by RaSCSI.

I believe this check was done to make sure that only CD-ROMs with Apple firmware were used.

There are a couple work-arounds:
- Install ResExcellence's CD-ROM driver hack (https://web.archive.org/web/20040404121044/http://www.resexcellence.com/hack_html_99/12-21-98.shtml)
- [Untested] Use a 3rd party CD-ROM driver. The CD driver that was distributed with Toast may be a good one to try.

erichelgeson, 2020-10-12:
FYI https://macintoshgarden.org/apps/cd-sunrise-v22b did not work with rascsi cd emulation

rdmark, 2021-08-17:
For the record, the Toast CD Reader driver from https://macintoshgarden.org/apps/astarte-toast-256 does not work either.  The extension just fails to load when testing on System 7.1 (Pro and P6) as well as Mac OS 7.6.1, even though a RaSCSI CD drive is attached.

rdmark, 2021-08-17:
One observation right now, is that since ResExcellence's hack is the only known (?) solution, and the oldest version of Apple CD-ROM that the hack is proven to work with is 5.4.2, effectively the oldest Mac OS version that can be used right now with RaSCSI CD-ROM is 8.1.
Today I spent a few hours trying to hack earlier Apple CD-ROM drivers without success. I also tried to use 5.4.2 with older system software versions, also without success.

rdmark, 2021-08-18:
I've got some good news:  After some research and testing today, I am glad to announce that I've found two 3rd party drivers that work well with RaSCSI:  RapidCD and CD/DVD Drive TuneUp 2.0.3
See my detailed test results here:  http://shorturl.at/wKNY9

My favorite is RapidCD, since it mounts CDs super fast, also can handle the DOS partitions, and is the only one that works on my stock Mac SE.  It even works on System 6.0.7, which blew me away!

uweseimet, 2021-08-21:
@rdmark It would be helpful to have a log on trace level for those cases where software fails to use the emulated devices.

rdmark, 2021-08-22:
@uweseimet This is an example when attaching an image and the system not being able to read the disk.  Hacked Apple CD ROM 5.3.1, System 7.1.1 on a Mac SE.

[2021-08-22 07:07:51.674] [info] Validating: cmd=ATTACH, id=4, unit=0, type=SCCD, filename='/home/pi/images/71.iso', device name='', params=''
[2021-08-22 07:07:51.676] [info] Executing: cmd=ATTACH, id=4, unit=0, type=SCCD, filename='/home/pi/images/71.iso', device name='', params=''
[2021-08-22 07:07:51.679] [info] Media capacity for image file '/home/pi/images/71.iso': 39067 blocks
[2021-08-22 07:07:51.681] [info] Added new SCCD device, ID: 4 unit: 0
[2021-08-22 07:07:51.810] [info] +----+----+------+-------------------------------------
[2021-08-22 07:07:51.813] [info] | ID | UN | TYPE | DEVICE STATUS
[2021-08-22 07:07:51.816] [info] +----+----+------+-------------------------------------
[2021-08-22 07:07:51.816] [info] |  3 |  0 | SCHD | /home/pi/images/600MB.hda
[2021-08-22 07:07:51.824] [info] |  4 |  0 | SCCD | /home/pi/images/71.iso (WRITEPROTECT)
[2021-08-22 07:07:51.825] [info] +----+----+------+-------------------------------------
[2021-08-22 07:07:52.668] [trace] virtual void SCSIDEV::Selection() Selection Phase ID=4 (with device)
[2021-08-22 07:07:52.668] [trace] virtual void SASIDEV::Command() Command Phase
[2021-08-22 07:07:52.668] [trace] virtual void SCSIDEV::Execute() Execution phase command $00
[2021-08-22 07:07:52.669] [debug] ++++ CMD ++++ virtual void SCSIDEV::Execute() ID 4 received CmdTestUnitReady ($00)
[2021-08-22 07:07:52.669] [trace] void SASIDEV::CmdTestUnitReady() TEST UNIT READY Command
[2021-08-22 07:07:52.669] [trace] Setting status: Sense Key: $06, ASC: $28, ASCQ: $00
[2021-08-22 07:07:52.669] [trace] BOOL Disk::CheckReady() Disk in needs attention
[2021-08-22 07:07:52.669] [trace] virtual void SCSIDEV::Error(ERROR_CODES::sense_key, ERROR_CODES::asc) Sense Key and ASC for subsequent REQUEST SENSE: $00, $00
[2021-08-22 07:07:52.669] [trace] virtual void SCSIDEV::Error(ERROR_CODES::sense_key, ERROR_CODES::asc) Error (to status phase)
[2021-08-22 07:07:52.669] [trace] void SASIDEV::Status() Status Phase $02
[2021-08-22 07:07:52.669] [trace] virtual void SCSIDEV::Send() sending handhake with offset 0, length 1
[2021-08-22 07:07:52.670] [trace] virtual void SCSIDEV::Send() Move to next phase status (8)
[2021-08-22 07:07:52.670] [trace] void SASIDEV::MsgIn() Starting Message in phase
[2021-08-22 07:07:52.670] [trace] void SASIDEV::MsgIn() Transitioning to Send()
[2021-08-22 07:07:52.670] [trace] virtual void SCSIDEV::Send() sending handhake with offset 0, length 1
[2021-08-22 07:07:52.670] [trace] void SASIDEV::MsgIn() Transitioning to Send()
[2021-08-22 07:07:52.670] [trace] virtual void SCSIDEV::Send() Move to next phase msgin (9)
[2021-08-22 07:07:52.670] [trace] virtual void SCSIDEV::BusFree() Bus free phase
[2021-08-22 07:07:52.672] [trace] virtual void SCSIDEV::Selection() Selection Phase ID=4 (with device)
[2021-08-22 07:07:52.672] [trace] virtual void SASIDEV::Command() Command Phase
[2021-08-22 07:07:52.673] [trace] virtual void SCSIDEV::Execute() Execution phase command $03
[2021-08-22 07:07:52.673] [debug] ++++ CMD ++++ virtual void SCSIDEV::Execute() ID 4 received CmdRequestSense ($03)
[2021-08-22 07:07:52.673] [trace] void SASIDEV::CmdRequestSense() REQUEST SENSE Command
[2021-08-22 07:07:52.673] [trace] virtual int Disk::RequestSense(const DWORD*, BYTE*) size of data = 18
[2021-08-22 07:07:52.673] [trace] Setting status: Sense Key: $00, ASC: $00, ASCQ: $00
[2021-08-22 07:07:52.673] [trace] void SASIDEV::CmdRequestSense() Sense Key $06, ASC $28
[2021-08-22 07:07:52.673] [trace] void SASIDEV::DataIn() Going into Data-in Phase
[2021-08-22 07:07:52.673] [trace] virtual void SCSIDEV::Send() sending handhake with offset 0, length 18
[2021-08-22 07:07:52.674] [trace] virtual void SCSIDEV::Send() Move to next phase datain (6)
[2021-08-22 07:07:52.674] [trace] void SASIDEV::Status() Status Phase $00
[2021-08-22 07:07:52.674] [trace] virtual void SCSIDEV::Send() sending handhake with offset 0, length 1
[2021-08-22 07:07:52.674] [trace] virtual void SCSIDEV::Send() Move to next phase status (8)
[2021-08-22 07:07:52.674] [trace] void SASIDEV::MsgIn() Starting Message in phase
[2021-08-22 07:07:52.674] [trace] void SASIDEV::MsgIn() Transitioning to Send()
[2021-08-22 07:07:52.674] [trace] virtual void SCSIDEV::Send() sending handhake with offset 0, length 1
[2021-08-22 07:07:52.675] [trace] void SASIDEV::MsgIn() Transitioning to Send()
[2021-08-22 07:07:52.675] [trace] virtual void SCSIDEV::Send() Move to next phase msgin (9)
[2021-08-22 07:07:52.675] [trace] virtual void SCSIDEV::BusFree() Bus free phase
[2021-08-22 07:07:52.676] [trace] virtual void SCSIDEV::Selection() Selection Phase ID=4 (with device)
[2021-08-22 07:07:52.676] [trace] virtual void SASIDEV::Command() Command Phase
[2021-08-22 07:07:52.677] [trace] virtual void SCSIDEV::Execute() Execution phase command $00
[2021-08-22 07:07:52.677] [debug] ++++ CMD ++++ virtual void SCSIDEV::Execute() ID 4 received CmdTestUnitReady ($00)
[2021-08-22 07:07:52.677] [trace] void SASIDEV::CmdTestUnitReady() TEST UNIT READY Command
[2021-08-22 07:07:52.677] [trace] Setting status: Sense Key: $00, ASC: $00, ASCQ: $00
[2021-08-22 07:07:52.677] [trace] BOOL Disk::CheckReady() Disk is ready!
[2021-08-22 07:07:52.677] [trace] void SASIDEV::Status() Status Phase $00
[2021-08-22 07:07:52.678] [trace] virtual void SCSIDEV::Send() sending handhake with offset 0, length 1
[2021-08-22 07:07:52.678] [trace] virtual void SCSIDEV::Send() Move to next phase status (8)
[2021-08-22 07:07:52.678] [trace] void SASIDEV::MsgIn() Starting Message in phase
[2021-08-22 07:07:52.678] [trace] void SASIDEV::MsgIn() Transitioning to Send()
[2021-08-22 07:07:52.678] [trace] virtual void SCSIDEV::Send() sending handhake with offset 0, length 1
[2021-08-22 07:07:52.678] [trace] void SASIDEV::MsgIn() Transitioning to Send()
[2021-08-22 07:07:52.679] [trace] virtual void SCSIDEV::Send() Move to next phase msgin (9)
[2021-08-22 07:07:52.679] [trace] virtual void SCSIDEV::BusFree() Bus free phase
[2021-08-22 07:07:52.680] [trace] virtual void SCSIDEV::Selection() Selection Phase ID=4 (with device)
[2021-08-22 07:07:52.680] [trace] virtual void SASIDEV::Command() Command Phase
[2021-08-22 07:07:52.681] [trace] virtual void SCSIDEV::Execute() Execution phase command $43
[2021-08-22 07:07:52.681] [debug] ++++ CMD ++++ virtual void SCSIDEV::Execute() ID 4 received CmdReadToc ($43)
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
uweseimet, 2021-08-23:
@rdmark The current uweseimet_develop branch contains additional debug output, which should reveal which code page MODE SELECT wants to change. Would be great if you provided updated logs whenever you have the time for it.

rdmark, 2021-08-23:
@uweseimet Do I need to compile rascsi with debug symbols to get the right level of debug output?

rdmark, 2021-08-23:
@uweseimet trace using b40c6b1 on my Mac SE, System 6.0.7, Apple CD-ROM driver.  Up through booting the system off a non-RaSCSI hard drive, the system complaining that the CD file system can't be read, and me hitting the Eject button.
[cd_trace2.txt](https://github.com/akuker/RASCSI/files/7034796/cd_trace2.txt)

uweseimet, 2021-08-23:
@rdmark Thank you for providing updated logs. At least from the new logs we know now which mode page the driver tries to use:

```
[2021-08-23 21:48:02.151] [debug] virtual bool Disk::Dispatch(SCSIDEV*) received CmdModeSelect ($15)
[2021-08-23 21:48:02.151] [trace] MODE SELECT for unsupported page 21
```

When (and if) somebody starts investigating this issue thsi piece of information might be useful.

akuker, 2021-12-30:
There's also an issue with ModeSense6. When the Mac sends the ModeSense6 command, it specifies a size of 0x14 (20 decimal). This graphic shows that RaSCSI doesn't respond to the ModeSense6 for Page 1 request. It transitions to an error status 2.
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

The current RaSCSI code calculates a response of size 24. This is too big, and I don't think RaSCSI is calculating the response size appropriately. The response size should be 20 bytes (as requested by the Mac).... 4 bytes (for the mode sense data header) + 8 bytes (for the block descriptor) + 8 bytes (for the error recovery parameters).

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

@uweseimet - I'm curious about your opinions on the risk associated with this change.

akuker, 2021-12-30:
Another interesting observation - With the Apple CD drive I was using, I didn't ever see a ModeSelect6 (15h) command in the SCSI data capture. I'm going to do some more data captures from some other drives to make sure this wasn't a fluke.

My wild theory? If the drivers get the data they expect from the Inquiry and/or ModeSense6 commands, it doesn't need to change anything using the ModeSelect command.

uweseimet, 2021-12-30:
@akuker Well, there is no risk if your change is compliant with the SCSI specification. If it is not the change will break a lot. In cases like this it is very important to check against the specification.

einstein95, 2022-06-16:
It appears you've got the wrong response for page 0x30 comparing it to the one in MAME (which does work with stock AppleCD drivers). See https://github.com/mamedev/mame/blob/badecba0e3aa372b75c738a4c53b2a7f8332064e/src/devices/bus/nscsi/cd.cpp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

rdmark, 2022-07-08:
@einstein95 Thanks for the tip! In addition to the MODE SENSE piece here, there seems to be an aspect of masquerading with a particular product string in the MAME solution: https://github.com/mamedev/mame/commit/c58e4b2a3e3624299da8362740c6c24a4c428abf

Closed 2022-09-10.

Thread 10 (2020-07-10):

HW: version 1.5 of RaSCSI has ACT signal miswired

akuker, 2020-07-10:
Version 1.5 of the RaSCSI "68kmla" version has an incorrect connection. Pin 1 should be connected to the "ACT" signal, instead of the PI-ACK signal.

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

Workaround:

Cut the trace of ACT running to pin 1 of U3. Scrape off some solder mask on the side near the via.
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

Solder a jumper wire from the trace to Pin 7 of the Raspberry Pi GPIO header.
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

akuker, 2020-07-10:
Tagged as "won't fix". When the next batch of boards (if ever) are ordered, this should be fixed.

phrax0, 2020-08-15:
With the development of the 1.6 board addressing this issue, we can close #10 now.  Also, thanks for doing the 1.6 board akuker!

akuker, 2020-08-16:
Agreed!

Closed 2020-08-16.

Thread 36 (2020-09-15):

Add ID EEPROM to RaSCSI board

quorten, 2020-09-15:
An ID EEPROM is recommended for Raspberry Pi HATs so that drivers can be automatically loaded when the corresponding HAT is connected, and automatically not loaded when a different HAT is connected.  In the particular case of RaSCSI, it would also facilitate indicating to the software whether the standard or fullspec board is connected and it could adapt accordingly.

quorten, 2020-10-23:
@akuker I'm wondering, which future board revision do you think it would be a good idea to work in the hardware changes to add this?  I'm willing to make the changes to add this to a future board revision, but since the boards you've designed are pretty crammed as-is I'm curious what your thoughts/ideas are.

Another thing, I feel like putting a README in the `hw` directory containing a brief description of each hardware revision and its history would be really helpful.

akuker, 2020-10-25:
I was thinking of starting a "3.0" board sometime in the future.

When I started digging into this a couple months ago, I thought I ran into a problem. It looked like the GPIO header pins for the HAT EEPROM conflicted with some of the pins used for RaSCSI signal lines. I haven't found a definitive specification on how this is supposed to be wired though.

Now that I'm double-checking this tonight, the Ki-CAD "Hat" template shows that the EEPROM data/clock lines go to pins 27/28 of the GPIO connector. These are currently unused in the RaSCSI design, so I don't know what I was thinking before.

The 2.7 version of the board originally had the EEPROM on it. There is an area in the center of the board that is wide open. That used to have the EEPROM on there. (Its probably still in some of the previous revisions in Git) You could also put the eeprom on the bottom of the board.

You are welcome to create a "3.0" version and see if you can get something going!

I like the README idea too. This information is available on the wiki https://github.com/akuker/RASCSI/wiki/Hardware-Versions . But, it'd be nice to at least have a README that points to it. I think I shall do that tonight

akuker, 2020-10-25:
@quorten - I guess I didn't look hard enough for the official documentation - https://github.com/raspberrypi/hats/

The camera flex cutout definitely wont fit without a major redesign. The display flex cutout might be do-able, but not sure its worth it.

quorten, 2020-10-25:
So I've started through the schematics, and I might have spotted a design oversight.

What was the particular problem that the Raspberry Pi 3.3v pull-up resistors were added to the RaSCSI board to solve?
 Normally using the software-configurable pull-up resistors inside the BCM SoC is sufficient.  A compelling reason to do otherwise should probably be accompanied with a note in the schematics since this is seen as a common beginner oversight with Raspberry Pi.

If I recall correctly, when the Raspberry Pi boots, all GPIO pins are initialized as outputs and then pulsed low-high-low, so using the pull-up resistors for the sake of pre-boot behavior is moot.  Raspberry Pi uses approximately 50k resistors for internal pull up/down.

akuker, 2020-10-25:
_What was the particular problem that the Raspberry Pi 3.3v pull-up resistors were added to the RaSCSI board to solve?_
Tbh - I'm not sure. They were on the original RaSCSI design, and I just left them there.

During runtime operation, the direction of the GPIOs is changing constantly, so perhaps the original developer ran into issues? I'm totally open to removing them if you don't feel they're necessary.

quorten, 2020-10-26:
So I'll put this quick observation out here, it appears that having two of the bus transceiver chips rotated around 180 degrees is non-ideal for early-boot behavior, rotating them back 180 degrees, switching the A and B sides, and negating the software assertion of the direction signals would allow the early boot assertion of the direction signals to be such that all the transceivers are put in input mode until the Raspberry Pi finishes booting.  That would definitely eliminate any need for the Raspberry Pi 3.3v pull-up resistors.  (Plus it would make assembly easier too.)

Another thing, I noticed that there are no bypass capacitors on this board, although there should be one 100 nF bypass capacitor for each transceiver chip.  (Of course, many early RPi HAT board revisions get away without this design best practice just fine.)

akuker, 2020-10-27:
For the current design, most of it was just copied from Gimons' original version. I wanted to get comfortable with the initial design before changing things. That being said.... I'm fine with changing things :)

> That would definitely eliminate any need for the Raspberry Pi 3.3v pull-up resistors.
Agreed, but it would drive changes to the software. Right now, there isn't a way for the software to know what board it is connected to. If we add the eeprom, that would allow the software to detect which way those chips are installed.

> I noticed that there are no bypass capacitors on this board, although there should be one 100 nF bypass capacitor for each transceiver chip.
I agree this would be a good update

uweseimet, 2022-08-26:
Any news after almost two years?

akuker, 2022-08-26:
Nope - Let's close it. If we decide to add an EEPROM at a later date, we can do it. But there aren't any immediate plans to do it.

quorten, 2022-08-27:
Bummer!  I would love to coordinate the inclusion some time in the future.  Sure, those two years were big news for me but not for this ticket.

uweseimet, 2022-08-27:
@quorten Just re-open the ticket when you are ready to start working on it.

Closed 2022-08-26.

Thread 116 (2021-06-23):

REQUEST SENSE returns Sense Key of 0 in case of unsupported SCSI commands

uweseimet, 2021-06-23:
This issue was observed with a Pi 4, github revision 54cf432, RaSCSI board version 2.3. Computer (initiator) is an Atari TT and an Atari Falcon with HDDRIVER 11 as hard disk driver and the SDRVTEST tool (https://github.com/uweseimet/atari_public/tree/main/SDRVTEST).

When rejecting unsupported SCSI commands (e.g. READ CAPACITY(16) with opcode 0x9e, but also others) the initiator does not receive CHECK CONDITION, even though SASIDEV::Status() is executed. There is also no CHECK CONDITION visible for the initiator when passing invalid block numbers (higher than the actual drive capacity) to READ(10). The logs do not show anything unusual.
There might be an problem with bus signal handling when sending the status byte.

Numerous real SCSI devices were tested in the same environment, and they all returned CHECK CONDITION as expected, which makes it likely that this is an issue with the RaSCSI software.

uweseimet, 2021-07-04:
Further analysis shows that CHECK CONDITION is actually sent, but the subsequent REQUEST SENSE returns a sense key of 0:

[2021-07-04 12:22:14.947] [trace] void SASIDEV::CmdRequestSense() REQUEST SENSE Command
[2021-07-04 12:22:14.948] [trace] virtual int Disk::RequestSense(const DWORD*, BYTE*) size of data = 18
[2021-07-04 12:22:14.948] [trace] void SASIDEV::CmdRequestSense() Sense key $00

uweseimet, 2021-07-04:
This issue is a major one for software that evalutes the sense key and ASC in order to learn about details of a failed command. Unless I am missing something currently an error is reported (CHECK CONDIDTION), but when such a piece of software wants to react on it, REQUEST SENSE says that that was no previous error, which is contradictory.

@akuker I have prepared a fix for this issue, but without my pending PR being reviewed (and hopefully approved) I cannot really proceed, because the code base in my PR branch and in develop has started to differ too much.

akuker, 2021-07-05:
@uweseimet - I've closed the PR and pulled in the changes. Thank you for all of the great fixes!

uweseimet, 2021-07-05:
@akuker Thank you for merging my changes. Please see PR https://github.com/akuker/RASCSI/pull/120, which resolves this issue.

Closed 2021-07-18.

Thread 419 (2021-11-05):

Mac Plus won't boot with SCDP attached

jcs, 2021-11-05:
# Info

- Which version of Pi are you using:
4B

- Which github revision of software:
cf9a578c82 (v21.10.01)

- Which board version:
FULLSPEC

- Which computer is the RaSCSI connected to:
Macintosh Plus

# Describe the issue

When attaching a DaynaPort SCSI/Link ethernet device via `rasctl` before booting the Mac, the Mac won't boot similar to issue #40 where it shows a black screen.  If the Mac is booted and the ethernet device is attached later, it works fine.  This makes it difficult to use RaSCSI for both a hard drive (SCHD) and ethernet (SCDP), since the SCHD device has to be attached before booting but the ethernet has to be attached after a delay.

I'm assuming the Mac probes the SCSI bus during boot while looking for hard drives and gets a weird response from the ethernet device just like in #40 where the Lido driver caused issues.

Perhaps there's a way to detect this activity and just ignore the probe in the ethernet device driver...

rdmark, 2021-11-05:
@jcs This is definitely not how it should work. I tried to reproduce on my Mac SE, but without success, so it may be a quirk of the Plus's infamously non-standard SCSI interface.

Just to throw a couple of thoughts out there:
Do you know which driver your hard drive image is using (Lido etc.)? Have you tried another boot volume hard drive image? Have you tried different SCSI ID assignments and orders of devices?

jcs, 2021-11-06:
The issue happens without any hard drive image attached. If I boot to a floppy or HD20 with the ethernet device attached in RaSCSI it goes to the black screen.

uweseimet, 2021-11-07:
@jcs Please add rascsi trace logs to this ticket, based on the simplest scenario (no drives attached) you can reproduce this issue with.

jcs, 2021-11-07:
````
$ sudo rascsi -L trace
SCSI Target Emulator RaSCSI(*^..^*) version 21.10.1 (Nov  5 2021, 01:18:54)
Powered by XM6 TypeG Technology / Copyright (C) 2016-2020 GIMONS
Copyright (C) 2020-2021 Contributors to the RaSCSI project
Connect type : FULLSPEC
[2021-11-07 12:11:39.599] [info] No images currently attached.
No images currently attached.
[2021-11-07 12:11:41.321] [info] Validating: operation=ATTACH, device id=6, unit=0, type=SCDP, device params='file=wlan0:10.10.20.1/24', 'interfaces=wlan0:10.10.20.1/24', vendor='', product='', revision='', block size=0
[2021-11-07 12:11:41.321] [info] Executing: operation=ATTACH, device id=6, unit=0, type=SCDP, device params='file=wlan0:10.10.20.1/24', 'interfaces=wlan0:10.10.20.1/24', vendor='', product='', revision='', block size=0
[2021-11-07 12:11:41.322] [trace] Opening Tap device
[2021-11-07 12:11:41.322] [trace] Opened tap device 7
[2021-11-07 12:11:41.322] [trace] Going to open ras0
[2021-11-07 12:11:41.323] [trace] return code from ioctl was 0
[2021-11-07 12:11:41.323] [info] rascsi_bridge is already available
[2021-11-07 12:11:41.323] [debug] ip link set ras0 up
[2021-11-07 12:11:41.323] [debug] brctl addif rascsi_bridge ras0
[2021-11-07 12:11:41.325] [trace] Getting the MAC address
[2021-11-07 12:11:41.325] [trace] Got the MAC
[2021-11-07 12:11:41.325] [info] Tap device ras0 created
[2021-11-07 12:11:41.325] [debug] Tap interface created
[2021-11-07 12:11:41.325] [trace] virtual bool SCSIDaynaPort::Init(const std::map<std::__cxx11::basic_string<char>, std::__cxx11::basic_string<char> >&) memset(m_mac_addr, 0x00, 6);
[2021-11-07 12:11:41.326] [trace] virtual bool SCSIDaynaPort::Init(const std::map<std::__cxx11::basic_string<char>, std::__cxx11::basic_string<char> >&) m_mac_addr[0]=0x00;
[2021-11-07 12:11:41.328] [info] Attached SCDP device, ID 6, unit 0

[ Mac Plus is booted here ]

[2021-11-07 12:12:18.011] [trace] virtual void SCSIDEV::Selection() Selection Phase ID=6 (with device)
[2021-11-07 12:12:18.011] [trace] virtual void SASIDEV::Command() Command Phase
[2021-11-07 12:12:18.011] [trace] virtual void SASIDEV::Command() Command Byte 0: $08
[2021-11-07 12:12:18.011] [trace] virtual void SASIDEV::Command() Command Byte 1: $00
[2021-11-07 12:12:18.011] [trace] virtual void SASIDEV::Command() Command Byte 2: $00
[2021-11-07 12:12:18.012] [trace] virtual void SASIDEV::Command() Command Byte 3: $00
[2021-11-07 12:12:18.012] [trace] virtual void SASIDEV::Command() Command Byte 4: $01
[2021-11-07 12:12:18.012] [trace] virtual void SASIDEV::Command() Command Byte 5: $00
[2021-11-07 12:12:18.012] [trace] virtual void SCSIDEV::Execute() Execution phase command $08
[2021-11-07 12:12:18.012] [debug] ++++ CMD ++++ virtual void SCSIDEV::Execute() Executing command $08
[2021-11-07 12:12:18.012] [debug] virtual bool SCSIDaynaPort::Dispatch(SCSIDEV*) Executing Read6 ($08)
[2021-11-07 12:12:18.012] [trace] virtual void SCSIDaynaPort::Read6(SASIDEV*) READ(6) command record=0 blocks=1
[2021-11-07 12:12:18.012] [trace] virtual int SCSIDaynaPort::Read(const DWORD*, BYTE*, uint64_t) reading DaynaPort block 0
[2021-11-07 12:12:18.012] [trace] virtual int SCSIDaynaPort::Read(const DWORD*, BYTE*, uint64_t) Read maximum length 0, (0000)
[2021-11-07 12:12:18.013] [trace] BOOL CTapDriver::PendingPackets() 1 revents
[2021-11-07 12:12:18.013] [debug] int CTapDriver::Rx(BYTE*) CRC is 77C7F92E - 2E F9 C7 77
[2021-11-07 12:12:18.013] [trace] virtual int SCSIDaynaPort::Read(const DWORD*, BYTE*, uint64_t) Packet Sz 134 (00000086) read: 1
[2021-11-07 12:12:18.013] [trace] BOOL CTapDriver::PendingPackets() 1 revents
[2021-11-07 12:12:18.013] [trace] virtual void SCSIDaynaPort::Read6(SASIDEV*) ctrl.length is 140
[2021-11-07 12:12:18.013] [trace] void SASIDEV::DataIn() Going into Data-in Phase
[2021-11-07 12:12:18.013] [trace] virtual void SCSIDEV::Send() sending handhake with offset 0, length 140
[2021-11-07 12:12:18.014] [trace] virtual int GPIOBUS::SendHandShake(BYTE*, int, int) DELAYING for 100us after 6 bytes
[2021-11-07 12:12:18.015] [trace] virtual void SCSIDEV::Send() Move to next phase datain (6)
[2021-11-07 12:12:18.015] [trace] void SASIDEV::Status() Status phase
[2021-11-07 12:12:18.015] [trace] void SASIDEV::Status() Status Phase $00
[2021-11-07 12:12:18.015] [trace] virtual void SCSIDEV::Send() sending handhake with offset 0, length 1

[ Mac Plus screen has gone black ]

[2021-11-07 12:12:24.010] [trace] virtual void SCSIDEV::BusFree() Bus free phase
````

uweseimet, 2021-11-07:
@jcs Thank you for the logs. Looks as if the driver does not check for the device type when booting but just treats the Daynaport like a hard disk drive and tries to read a sector from the Daynaport, using Read(6), which is a SCSI command for reading sectors. But for the Daynaport Read(6) reads packets, not sectors. In your log the Daynaport device as response to the read request returns 140 bytes, but the Mac expects a full sector (512 bytes), which it never gets. The Mac should notice that there are no more data because the SCSI status phase is entered, but it appears as if the Mac keeps on waiting.
Somebody with more insight into the Daynaport code might be able to tell more, but IMHO the problem is not caused by RaSCSI but by the Mac trying to read a sector from a non-hard disk device, and then not being able to cope with getting less data than expected, even though the SCSI bus signals indicate that all available data have been transferred.

rdmark, 2021-11-07:
@jcs Have you installed the DaynaPort Mac driver, and which version? Also, which version of the System Software / Mac OS are you running?

jcs, 2021-11-08:
I have installed the Mac driver on the hard drive image I boot with, and it works fine as an ethernet device if it's attached after booting.  But with both devices attached at boot, it never gets as far as booting from the hard drive image.

This is System 6.0.8.
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
marciot, 2021-11-08:
@rdmark: I saw somewhere in the RaSCSI documentation where it was not recommended to run RaSCSI and Netatalk on the Pi Zero due to performance limitations. Has this changed?

Anyhow, I am curious to hear your workflow, but I feel like running an AppleShare server on the Raspberry Pi itself would be of limited utility for me, as then I would have to get files out of Basillisk II and SFTP them over to the Raspberry Pi, maybe using .hqx or something to preserve the resource fork. Generally I like using Basillisk II to unpack archives, extract disk images and do all the fiddling with the files prior to sending them over to my Mac Plus. Right now I do this by mounting a disk image in Basillisk, modifying it, uploading it to the RaspPI, and mounting it on the Mac Plus. I think if my Basillisk II was an AppleTalk server, I would be able to simply copy the extracted files into the server directory and have them show up on my Mac Plus. That would be amazing!

rdmark, 2021-11-08:
@marciot To give you a short answer: I also like to use Basilisk in the way that you describe. Basilisk II is able to connect to the same Netatalk server (over TCP only) running on the Pi. Netatalk is smart enough to save the resource fork on the Linux file system as separate files, and then merge them back together when copying back to a Mac. It works totally seamlessly.

But yeah, the Zero might struggle. Maybe you can run it on another Linux machine (or VM).

Anyhow, let's stop getting off topic here. The https://tinkerdifferent.com/ forums could be a good place for these topics!

uweseimet, 2021-11-08:
@jcs Instead of returning dummy data (which may cause issues with other drivers and does not look like a clean solution) in https://github.com/jcs/RASCSI/commit/cc68528fa5fdd57c4471d7d0120b92fc534b2c0c, does it also work if you report a proper SCSI error instead, e.g. DEVICE NOT READY? After all, that's what it is, if you want to access a device that is not initialized yet. I'm quite sure the Mac will react correctly on this, because the same can happen if a removable media drive, e.g. a ZIP without media, is present.

jcs, 2021-11-08:
Thanks @uweseimet, returning `ERROR_CODES::sense_key::NOT_READY` in `SCSIDaynaPort::Read6` works well for the Mac Plus.  I'll look into checking the CDB byte as a way to un-initialize.

uweseimet, 2021-11-08:
@jcs Sounds good Depending on your results when can decide on the best approach, NOT_READY is most likely the best, because it reflects the Daynaport status and appears like a clean solution to me.

jcs, 2021-11-08:
@uweseimet That approach did seem to work better and is a [much smaller change](https://github.com/jcs/RASCSI/commit/21cfe9494489a1bcf85b26b3001fc4e9deefa0b4).

It took me a while to figure out why the CDB control value test wasn't working in `SCSIDaynaPort::Read`.  The cast of the `cdb *` data to a `scsi_cmd_read_6_t` struct is bogus because the data in `cdb *` is not packed raw SCSI data (each DWORD was manually copied into `cmd`) before this function.  If you print out each value of the `scsi_cmd_read_6_t` struct after the cast, you'll see that the fields after `operation_code` are all zero.  This seems to be the only driver and function that tries to put CDB data back into a SCSI command type, and it's only used to fetch two fields, so it might be easier just to avoid doing this altogether.  I made a [separate commit](https://github.com/jcs/RASCSI/commit/328fc162588ebf57da02584f7184e446ae1e1103) for that.

If either of these two changes are wanted, I can make separate pull requests for them.

uweseimet, 2021-11-08:
@jcs I suggest to use the NOT_READY approach. This one is clean and straightforward. The device is not ready, and it tells the SCSI initiator so by using the error code reserved for such a case. With the CDB approach we would rely on undocumented (there is no official documentation for the Daynaport) behavior, which might have side effects
Can you please prepare a PR with the NOT_READY change?

jcs, 2021-11-08:
Fixed via f2b5d86

Closed 2021-11-08.

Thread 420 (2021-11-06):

[Troubleshooting] My canary is starving! :sob:

marciot, 2021-11-06:
# Info

- Which version of Pi are you using: Raspberry Pi Zero W
- Which github revision of software:   October 2021 Release
- Which board version: 2.4a
- Which computer is the RaSCSI connected to: Mac Plus

# Describe the issue

Hey guys, thanks for the help getting me sorted out with the `./easyinstall.sh`. I am now making some progress, but RaSCSI seems somewhat unreliable at this point and needs some debugging.

First off, a question to make sure I didn't mess this part up:

 -- How do I properly configure termination? There were two switches on the board, but I can't find info on whether to toggle one or both. Since I am daisy chaining RaSCSI after another SCSI device, I guessed that both switches needed to be on.

Anyhow, I was able to get my Mac to recognize a drive, but eventually it froze during a copy. This is what I get in the logs:

```
Nov 05 17:55:41 raspberrypi RASCSI[367]: [2021-11-05 17:55:41.921] [info] Validating: operation=ATTACH, device id=6, unit=0, type=SCHD, device params='file=System_7_Boot.hds', vendor='', product='', revision='', block size=0
Nov 05 17:55:41 raspberrypi RASCSI[367]: [2021-11-05 17:55:41.924] [info] Executing: operation=ATTACH, device id=6, unit=0, type=SCHD, device params='file=System_7_Boot.hds', vendor='', product='', revision='', block size=0
Nov 05 17:55:41 raspberrypi RASCSI[367]: [2021-11-05 17:55:41.925] [info] Attached SCHD device, ID 6, unit 0
Nov 05 18:06:58 raspberrypi kernel: sched: RT throttling activated
Nov 05 18:06:58 raspberrypi rtkit-daemon[721]: The canary thread is apparently starving. Taking action.
Nov 05 18:06:58 raspberrypi RASCSI[367]: [2021-11-05 18:06:52.757] [error] virtual void SCSIDEV::Receive() Not able to receive all data. Going to error
Nov 05 18:06:58 raspberrypi rtkit-daemon[721]: Demoting known real-time threads.
Nov 05 18:06:58 raspberrypi rtkit-daemon[721]: Successfully demoted thread 720 of process 720 (n/a).
Nov 05 18:06:58 raspberrypi rtkit-daemon[721]: Demoted 1 threads.
Nov 05 18:10:03 raspberrypi systemd[1]: Starting Cleanup of Temporary Directories...
Nov 05 18:10:04 raspberrypi systemd[1]: systemd-tmpfiles-clean.service: Succeeded.
Nov 05 18:10:04 raspberrypi systemd[1]: Started Cleanup of Temporary Directories.
```

I suspect "**RT throttling activated**", "**The canary thread is apparently starving.** Taking action." and "**Not able to receive all data. Going to error**" are all bad things :cry:

Anyhow, just for fun, here is a picture of my first test using RaSCSI. This is gonna rock once all the kinks are worked out! :grin:

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

marciot, 2021-11-06:
I have been disabling a bunch of services and uninstalling things, and while I am getting further in the copy than before, it still eventually fails with this error. Is the Raspberry Pi Zero W sufficiently powerful for RaSCSI?

Is there anyway to format a disc so that the Mac Plus won't write to it as fast? For some odd reason, my go-to formatting tool "Special Apple HD Setup 7.3.5" was not recognizing the RaSCSI disk, so I ended up using something called "Blue Disk Manager". I wonder if that has something to do with the problem. What is the recommended tool for 68k Macs?

Another weird symptom: If I try booting my Mac Plus with a RaSCSI disk attached, the Mac Plus wigs out, makes a strange sound, and the screen goes all garbled. Detaching the RaSCSI disk allows it to start.

rdmark, 2021-11-06:
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
@marciot Sorry to hear that you're having some challenges here. Let us help you work through them! I have two RaSCSI setups with original Zero Ws and it works perfectly with my SE and other later Macs, so this should not be the blocker at all.

> Is there anyway to format a disc so that the Mac Plus won't write to it as fast? For some odd reason, my go-to formatting tool "Special Apple HD Setup 7.3.5" was not recognizing the RaSCSI disk, so I ended up using something called "Blue Disk Manager". I wonder if that has something to do with the problem. What is the recommended tool for 68k Macs?
>

The Mac Plus has an early non-standards compliant SCSI implementation, so it is known to be picky about hard disk drivers in particular (not limited to RaSCSI.) The one driver to avoid with the Plus is Lido, but I don't think Blue Disk Manager is a known compatible one either.

The driver that I personally like to use is Silverlining, but to be safe you can use patched versions of Apple's tools to use the official drivers that are a bit slower but perhaps more compatible (perhaps.)

See the wiki for more info: https://github.com/akuker/RASCSI/wiki/Drive-Setup#Initializing_a_new_disk_on_Classic_Mac_OS

> Another weird symptom: If I try booting my Mac Plus with a RaSCSI disk attached, the Mac Plus wigs out, makes a strange sound, and the screen goes all garbled. Detaching the RaSCSI disk allows it to start.

This sounds suspiciously like how the Plus behaves when you attempt to boot off a drive using the Lido drivers, as mentioned above. See https://github.com/akuker/RASCSI/issues/40 for details. Did you by any chance use the easyinstall.sh to create the drive image you're trying to boot off?

marciot, 2021-11-06:
Okay, this is weird:

1. Using "Lido 7" to format the disk rather than "Blue Disk Manager" allows me to copy files to RaSCSI without triggering the RT Throttling.
2. Turning off my external HD (making it so the RaSCSI is the only powered on device in the SCSI chain), allows my Mac to boot properly from RaSCSI.
3. Once booted, I can power on my APS HD, use SCSIProbe 3.5 to mount it, and copy files back and forth with no issues.

So, even though it seems to involve some weird workarounds, I now have a way to boot my Mac Plus from RaSCSI and copy files to and from my external HD. So I consider it a success! :grin:

BTW, this is they type of screen I get when I try booting my Mac with RaSCSI and my external HD powered on. It's like a fractal pattern, kind of pretty:

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

marciot, 2021-11-06:
@rdmark: I posted that before I read your message. It's funny that so far I have made more progress with Lido than I did with Blue Disk Manager. I'll have to try Silverlining.

I believe I have the patched version of Apple HD Setup, what I have is called "Special Apple HD Setup 7.3.5", but it refuses to see the RaSCSI drive at all :shrug:

marciot, 2021-11-06:
So I am having difficulties coming up with a strategy for copying Silverlining to my Mac Plus. It doesn't look like RaSCSI disk images can be mounted in Basillisk II. Is there any other way to mount RaSCSI disk images so that you can copy files directly into it?

In the past I have used a Zip drive on a PowerBook to transfer files to my Mac Plus, but lately it has been suffering from clicks-of-death, so I would rather avoid using it as much as possible.

marciot, 2021-11-06:
Nevermind, I got Basillisk II to see the drive.

marciot, 2021-11-06:
@rdmark: I was able to format my RaSCSI partitions with Silver Lining. My Mac Plus still gets a garbled screen when I try booting with a RaSCSI device attached and my external drive powered on. I can boot fine when my external drive is powered off, and I can always use SCSI Probe to mount my external drive after the fact. It's pretty much the same result I was getting with Lido 7.

rdmark, 2021-11-06:
@marciot The question that you always have to ask:  Have you made sure the SCSI bus is terminated correctly? What is the order of the devices in the chain, and how is it terminated?

marciot, 2021-11-06:
@rdmark: I have the Mac Plus, connected to one SCSI connector on my external hard drive (termination switch off); the other SCSI connector on the external hard drive is connected to the RaSCSI (termination SW on).

marciot, 2021-11-06:
To wrap up this ticket, I have confirmed that the "RT throttling activated" and "The canary thread is apparently starving" problem only happens when using "Blue Disk Manager". Something in particular about that disk driver must put RaSCSI into a state where the real time task fails or takes too long to execute. While this may indicate a latent bug in the RaSCSI code, I imagine it isn't a high priority as Lido and Silver Lining seem to work just fine.

The boot/termination issue is unrelated to this ticket and is something I am still working on. The developer's can close this ticket as "Won't fix," if they do not wish to follow up on the problem with Blue Disk Manager.

rdmark, 2021-11-06:
@marciot Thanks for reporting back and providing all this context! Others can learn from this and not choose Blue Disk Manager with their Plus. :)

The two things I can think of regarding the problem when using RaSCSI with your external drive are:  Poor contacts in the SCSI cable and ports. You can try to get some contact cleaner solution in there and work it in. I've had weird SCSI instability issues with my old Macs that were simply due to oxidation on contacts leading to signals not getting through properly.

And secondly, the power supply on your external hard drive may be failing and providing out of spec voltages on the SCSI bus. You may want to open it up and test the voltage rails under load (while being careful with mains voltages, of course. ;) )

Anyhow, while I have your attention, may I ask you a favor? Did you by any chance test the DaynaPort ethernet adapter emulation with your Plus? We've had reports that it's not working properly, but I don't have access to a Plus myself. If you're up for it, I can walk you through how to get started. And besides, it's super neat to get your old Mac online, if just for the novelty factor.

marciot, 2021-11-06:
@rdmark: Yes, I hope to eventually work on getting DaynaPort running, but I need a break :) I already had a super busy day fiddling with retro hardware. Found out my Iomega Zip 100 Plus (SCSI + Parallel) had succumbed to the dreaded click of death, so I ended up taking the drive mechanism out of a Zip 100 drive (parallel-only) and transplanting it into the Zip 100 Plus. I then went down a rabbit-hole trying to get the Zip testing utility [Trouble in Paradise](https://www.grc.com/tip/clickdeath.htm) to test my refurbished drive. I installed SoftWindows 95 on a PowerBook 3400c and hooked up the Zip drive, and even though I could run TIP, it failed to see the SCSI Zip 100 Plus drive, even though SoftWindows 95 is *supposed* to allow access to SCSI devices. So now I am pretty much stuck trying to find a PC with a parallel port so I can test my refurbished drive using TIP. Oh wey!

rdmark, 2021-11-06:
@marciot Take your time! Once you get around to it, I'd love to hear back from you about your success or failure. As I mentioned in the other ticket, you can join the Discord channel for real-time conversations with other RaSCSI users.

marciot, 2021-11-08:
@rdmark: I began fiddling with the DynaPort drivers. See my comment on the thread #419

Closed 2021-11-06.

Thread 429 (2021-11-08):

[Feature Request] Mounting Floppy Images as SCSI drives?

marciot, 2021-11-08:
I know SCSI disks and floppies are totally different things (AFAIK the SCSI drive image has a boot record, a driver and partition table), but I wonder if you could start with a blank SCSI disk image of the appropriate size and have RaSCSI copy the data from the floppy into the SCSI disk image at just the right place so it over-writes the empty partition and presents a valid SCSI drive. There is a bit of complexity involved in dealing with the various types of disk images, such as header-less disk images or DiskCopy 4.2 disk images, but I think those issues can be solved (I've written code to translate from one type of disk image to another before).

marciot, 2021-11-08:
PS: I know it's kind of rude to ask for niche features, as if the developers don't already have enough on their plates, maybe I should re-phase this as "what could I do to help come up with something like this?"

I think I could probably try writing some C or Python code that converts a floppy disk image into a SCSI disk image, especially if I can find the appropriate documentation of the SCSI disk layout. If I can come up with some code that does it, could it be incorporated into RaSCSI easily?

I notice the feature matrix suggests the SCSI2SD is the only device that currently does this. Does anyone know how they do it or whether their code is open source?

rdmark, 2021-11-08:
@marciot This is certainly an interesting feature idea. What are the use cases that you have in mind? Booting software that can only run off a floppy boot disk?

Of interest to you may be the research done on the [Iomega Floptical](https://github.com/akuker/RASCSI/wiki/Iomega-Floptical) SCSI drive that also was compatible with standard magnetic floppy disks. I played around with it briefly a few weeks ago, and was able to get the Iomega drivers to load and recognize the drive, but that was as far as I got. I didn't try very hard though, to be honest.

You can play with it by attaching a removable drive with the correct INQUIRY strings, f.e.:

rasctl -i 2 -c attach -t scrm -n "IOMEGA:Io20S         *F:PP33" -f /path/to/image/file

Pacjunk, 2021-11-08:
This reminds me, I should add the DEC SCSI floppy drives to the drive properties table...  (not that they're terribly usable, but just for completeness)

marciot, 2021-11-10:
> @marciot This is certainly an interesting feature idea. What are the use cases that you have in mind? Booting software that can only run off a floppy boot disk?

Well, I'm fairly certain that if software can't run off a floppy boot disk, such as something like Dark Castle, then it won't boot of a SCSI device because of the SCSI driver. Rather, my use case is that I spend a lot of time using disk images for emulators, such as vMac or PCE (I am the curator of the [RetroWeb Vintage Computer Museum](http://retroweb.maclab.org/)). Having to convert all my pre-existing image files is rather time consuming, so being able to load them into RaSCSI immediately would be amazing.

> Of interest to you may be the research done on the Iomega Floptical SCSI drive that also was compatible with standard magnetic floppy disks.

I'll play around with it, but if it requires extra drivers then it would not exactly be compatible with pre-made disk images.

Is there are reason this device isn't available through the web UI yet?

rdmark, 2021-11-10:
> Is there are reason this device isn't available through the web UI yet?

No particular reason. I simply found out about it after putting together the initial list. If you create a PR against develop I'd be happy to accept it.

BTW, that is a very neat museum website you have there! Great work!

marciot, 2021-11-10:
The disk image situation is pretty much a mess when it comes to emulators, which makes inter-operability very difficult. When it comes to floppy disk images, there are "raw" headerless images and images with DiskCopy 4.2 headers. Most generally supported is 800k and 1.4MB images, but Mini vMac in particular throws a wrench into the equation by patching the ROM at runtime to load arbitrarily sized images as a floppy device. Other emulators, such as Basillisk II or PCE only support arbitrarily sized images as SCSI disks with a partition table, which is what RaSCSI does, but Mini vMac does not emulate SCSI at all. So all in all it leads to a situation when making one disk image that runs across the board is pretty much impossible.

rdmark, 2021-11-12:
Made a PR myself so that I doesn't get forgotten. https://github.com/akuker/RASCSI/pull/453

And yes, I looked into the Mini vMac disk image format a while ago, since it is such a popular format for image files floating around on the Net. Supporting it out of the box in RaSCSI would be hugely convenient. But it's not really documented (AFAICT) and non-standard, so it doesn't seem feasible at a glance, unfortunately.

rdmark, 2021-11-27:
For the record, I was able to use the Iomega Floptical driver for Mac (Mac OS 8.6) to mount an existing 1.44MB floppy image as a SCRM type RaSCSI drive and read data from it.

It isn't able to format a new floppy disk image, but reading the specs for the original device, this is not something that I think it supported in the first place.

Also, it doesn't seem to recognize Mac OS's eject command, which again is expected since the original device had a manual eject mechanism. This means you cannot use multi-disk installers this way, as the OS won't recognize that you've injected a new disk image after forcing an eject from the RaSCSI side.

Anyhow, this is a very limited usecase for Macs using this particular Iomega driver and device profile, but it does mean that Mac users have a path to easily extract data from single floppy disk images.

marciot, 2021-11-27:
@rdmark: That is very cool. Of course, all that makes me wonder if we can somehow locate documentation on how to write a device driver without those limitations. At least after my adventures with my Trouble in Paradise port, I have a good understanding how to write SCSI code on the Mac.

rdmark, 2021-11-29:
> This reminds me, I should add the DEC SCSI floppy drives to the drive properties table... (not that they're terribly usable, but just for completeness)

@Pacjunk Have you tested that an emulated DEC SCSI floppy drive actually works on your systems, and you can read floppy disk images this way? We're preparing release notes and I'd like to know what kinds of claims we can make. :)

Pacjunk, 2021-11-29:
Yes, I tested it - only under VMS though. The DEC systems just treats a floppy as a small hard drive, except they are removable. You still have to manually mount and dismount them in the operating system, but you have to do this with real drives too. I don't really recall using floppy drives for any serious purpose on those machines. Software always came on tape, or CD-ROM. Floppies were used occasionally on the alpha systems for firmware/ECU updates, but they may have been in FAT format as Alphas can switch to an ARC console if required. I didn't test this functionality.

Closed 2022-02-23.

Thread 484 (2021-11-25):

Heat question for SN74LS641-1

timmcross, 2021-11-25:
# Info

- Which version of Pi are you using:  3B+
- Which github revision of software: master
- Which board version: 2.4a
- Which computer is the RaSCSI connected to: p4 1.5GHz, Adaptec 2940, WinXP

# Describe the issue
First off, great project!  Built the board from the ground up and worked the first time!

One thing I noticed was that the SN74LS641-1 chips get quite hot during operation.  Is this expected?  Would small heatsinks be recommended?

Thanks, Tim

rdmark, 2021-11-26:
@timmcross The transceivers do run hot! They're rated for 70C, and anecdotally they run fine naked. If you have room for them, heatsinks probably won't hurt though!

See this post for more details: https://68kmla.org/bb/index.php?threads/rascsi-development-thread.6868/post-426873

Pacjunk, 2021-11-27:
Here's mine. I use "RAM chip heatsinks". They still get quite hot, but anything is better than nothing. Haven't had any problems running for several hours.

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
.

hsiboy, 2021-11-30:
Yeah, mine run hot and sing! Depending on what Rascsi is doing, i can hear a faint whine coming from them.

rdmark, 2021-11-30:
Added an FAQ entry for this. Closing out this ticket! https://github.com/akuker/RASCSI/wiki/FAQ

schreinerman, 2023-01-10:
I'm using the FULLSPEC 2.4a board. Seems to be the heat in the system is generated by an high frequency oscillating ground plane or power supply. In addition the terminator circuit is also not the best and is drawing about 200mA (!) Unfortunately the 5V track width is not that wide. The decoupling capacitors are also missing, so the drivers are getting an unfiltered power input (high frequency noise/oscillation). Silicon and high frequency is generating a lot of heat....

So I will try to ad decoupling capacitors, powering terminal power with 3.3V (better 2.8V) via 220 Ohms, bridge ground planes with extra wires to minimise ground plane oscillation

Closed 2021-11-30.

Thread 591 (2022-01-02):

Alternative to SN74LS641-1DW

DottiestDuke47, 2022-01-02:
I ordered some Bare PCBs of the rascsi from JLCPCB, and was checking the price and availibility of the other parts. I found that the SN74LS641-1DW is discontinued and very expensive, so went looking for alternatives. My question is, is the 74HCT245 a viable alternative?

akuker, 2022-01-05:
Hi @DottiestDuke47 - There is a discussion about several different transceiver options here: https://github.com/akuker/RASCSI/wiki/Transceiver-Comparison

The 74HCT245 looks like it is designed to sink a maximum of 35mA, while the SCSI spec calls for 48mA.

In practice, the 74HCT245 would _probably_ work. You would be running it outside of its design tolerances, so it will likely shorten the life of the part or you may have unreliable data.

I don't believe the SN74LS641-1 is discontinued. It has been impacted by the chip shortage though. Texas Instruments still has them available:
https://www.ti.com/store/ti/en/p/product/?p=SN74LS641-1DW

I purchase these transceivers in bulk. So if you're having trouble finding them, I can share what I have.

DottiestDuke47, 2022-01-05:
Thanks for taking the time check and reply to my question - I really appreciate it. Once I receive the PCBs, I will try to assemble them with the chips I have, if they do not work, is there a way I can get in touch to purchase so chips off you?

akuker, 2022-01-06:
Sure. Feel free to email me. My email is the same user name at gmail.com.

akuker, 2022-01-06:
Placing this issue "on hold" until @DottiestDuke47 is able to check out their new PCB design.

akuker, 2022-01-06:
Merging Issue #577 into this issue.

From @WarlockD

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

akuker, 2022-01-06:
Comment from @marciot on Issue #411 :

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

DottiestDuke47, 2022-01-19:
So i received the boards yesterday and populated them with the 74HCT245D transceivers, and to my amazement it worked. I tested with a Macintosh SE for about ~45 minutes, everything functioned fine. I'm not too cure about the long term effect of overrunning this chip, but since this is my first vintage mac, I'll be spending a lot of time exploring using this RaSCSI so I can report if anything out of the ordinary happens.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

DottiestDuke47, 2022-01-19:
Once again thanks a lot for your help @akuker 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

DottiestDuke47, 2022-01-19:
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

With regards to this, how would you control the actual direction of data transfer? On the original raSCSI project, there was a method where you could directly attach a scsi cable to the pi, but the logic levels could fry it, this leads me to belive that we dont need control of A-B B-A but just hi and low level data transfer.

akuker, 2022-01-30:
> So i received the boards yesterday and populated them with the 74HCT245D transceivers, and to my amazement it worked. I tested with a Macintosh SE for about ~45 minutes, everything functioned fine.

Thank you for reporting back @DottiestDuke47 - Do the chips get very hot while you're using them?

DottiestDuke47, 2022-02-02:
They did get warm but I wouldn't say very hot.

akuker, 2022-02-12:
I spent some time working on this page tonight:
https://github.com/akuker/RASCSI/wiki/Transceiver-Comparison

SN74ABT245B does look like a potential alternative!

I'm going to give this one a try: [SN74F245DW](https://www.ti.com/lit/ds/symlink/sn74f245.pdf?)

thbreidenbach, 2022-02-12:
The abt drivers are among the fastest I know. I wonder what actually limits the speed of the rascsi implementation. But alas the abt drivers are available and since I have a few here I’ll give it a go and report back.

Thanks for the great work!!

Yours Thorsten

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

akuker, 2022-02-12:
I believe the main limitation with RaSCSI is the speed of the GPIO access. The non-determinism of the Linux kernel doesn't help either. In this way, something like BlueSCSI or SCSI2SD have an advantage. They don't have the overhead of an operating system.

But, at the same time, they don't have the BENEFIT of an operating system either. Without an OS, things like the Daynaport emulation and the web interface would be much more difficult to implement.

thbreidenbach, 2022-02-12:
I tried the Baremetal implementation on a raspi 3A+ in a fullspec RaSCSI which did 1.3MB/sec on an Amiga 500 with Oktagon 508 with Oktapussy ROM and a reasonable fast Accelerator (35Mhz 68ec020)..
I might swap in an ***@***.*** to see if the Computer limits the speed.

The Zorro 2 Interface of the Amiga should offer something around 3.5MB/sec throughput. A Zorro 3 SCSI Card will be available soon since the A4091 Fast-SCSI 2 Controller is in the process of being reverse engineered. This Card should offer Speeds beyond 16MB/sec.

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

WarlockD, 2022-03-03:
Ugh I got to check my notifications more often,  Its been a fun few months:P  Anyway the NTS0104 seem to work fine using the pi, but I didn't have time to do any kind of board mock up, but the showed a nice edge on both the 5v and 3 volt size.  That being said, it was a month or so ago and need to rebuild my experiment.

Honestly, the hard IRQ kill that RaSCSI does is probery the best idea.  Its not clean by any means, but there isn't alot of ways you can turn off the scheduler in linux without replacing it completely.  The best way would be to make this a kernel module.  This way it can dirrectly fiddle with the kernel during transfers.

To be honest though, I kind of had to switch to using an ncr53c80.  I am trying to emulate a old tape drive and I HAVE to handle reconnection correctly and as a plus it handles the REQ/ACK easy using the dma pins.

Honestly I kind of wish those old 5V tolernt FPGA's were still around:P

WarlockD, 2022-03-10:
Oh found another.  Seems like it supports auto direction detection, 8-bit port.  NTS0308E.  Push pull is 20mbps but open drain is only 2mbps.  They aren't to bad at 1k@ US$0.54.  Humm, might be fine, max properation delay is 20ns humm, I think the 2 mbps is only in regards to lower votage trasistions and might be fine at 3.3v.  Ah well, I am going to buy a bunch a do some tests.

As for fast scsi-2, its possible, but may not be?  These older controllers usually fudge quite a bit on sync and give way more leway than a more modern controller.  If you kill the irq to the kernel so only your function is running, I think the delay is around 100ns so it MAY be possible as it only matters on the data transmission.

OH now THIS is intresting.  NVT2010PW is a TSSOP-24, but its a 10bit auto detecting votage between 1-5V.  goes up to 33mhz.  Going to get a few of these as well.

akuker, 2022-03-14:
NVT2010PW does look interesting....

akuker, 2022-03-17:
More data!!!!

I did some testing with the SN74F245, SN74ALS245A-1 and SN74LS641-1 (as a baseline).

| Device | Max Read | Max Write | Cost each |
| ------- | ---------- | -------------| ------------|
| SN74LS641-1 (baseline) |  950 KB/sec | 506KB/sec | [$3.66](https://www.digikey.com/en/products/detail/texas-instruments/SN74LS641-1DW/1590740)
| SN74F245 | 1245 KB/sec | 574 KB/sec | [$0.93](https://www.digikey.com/en/products/detail/texas-instruments/SN74F245DWR/276824) |
| SN74ALS245A-1 | 1193 KB/sec | 571 KB/sec | [$1.49](https://www.digikey.com/en/products/detail/texas-instruments/SN74ALS245A-1DW/13479511) |

Here are the waveforms of the D0 data line during a read operation:
**SN74F245**
Max Read: 1245 KB/sec
Max Write: 574 KB/sec
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
**SN74ALS245A-1**
Max Read: 1193 KB/sec
Max Write: 571 KB/sec
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
**SN74LS641-1**
Max Read: 950 KB/sec
Max Write:
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

Tests were done with a Raspberry Pi 4, 8GB RAM, running a 22.03 development build. RaSCSI version 2.4a and Digilent Analog Discovery 2 for the O-Scope. The Test PC was a Macintosh SE/30 using SCSI Director 4.0.

akuker, 2022-03-17:
From this data, I'm really leaning towards the SN74F245. The cost can not be beat. Especially since its available from JLCPCB as an assembly option. I'm still going to do more testing, and I'm open to other opinions!

uweseimet, 2022-08-26:
Any news on this?

akuker, 2022-08-26:
Yes, the new boards are sitting on my desk. I just need to finish testing them.

uweseimet, 2022-08-26:
Good news!

thbreidenbach, 2022-10-11:
I have ordered some older production date 74abt245 (100 I believe)
Would you like to check those too? They’re quite readily available (at least from me..)

Thorsten

Von meinem iPhone gesendet

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

jameswood, 2023-08-09:
> FYI: I ordered a FLIR camera so that I can take some temperature measurements between the SN74F245 and SN74LS641-1. This has been my one remaining concern with the SN74F245. I'll report back when I have more data!

How did you get on with this? I'm using the `SN74F245DW` and they run *hot!* Did you find the same? (I may also have some other problem, of course)

Is the recommendation still to use the `SN74LS641-1DW`?

akuker, 2023-10-14:
I'm closing this ticket, since I'm no longer able to spend time on it. The current recommendation is still to use the SN74LS641-1. The heat issues go away when supplying the SN74LS641-1 with a VCC of 3.3v instead of 5v. However, this is running the chip outside of its advertised limits. I haven't had any issues with it though.

So, in summary, SN74LS641-1DW is still the recommendation.

Closed 2023-10-14.

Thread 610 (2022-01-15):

Cant create a 10MB , IMAGE.HDS with Block Size: 256 bytes

CBMD9090, 2022-01-15:
# Info
- Which version of Pi are you using:  Pi 3B+ with Raspberry Pi OS Lite (image from Github)
- Which github revision of software: 21.11.1
- Which board version: Full spec
- Which computer is the RaSCSI connected to: Commodore D9090 Hard Drive - SASI Controller.
- D9090 Hard Drive info:  SASI Controller connected to a TM603S 10MB MFM Hard Drive. Its DOS only Formats about 7.5MB of the 10MB. It uses the following fixed specs:
- Cylinders 153 (0-152), Heads = 6 (or can be set to 4)
- Sectors per Cylinder/Track = 32 , Bytes per Sector = 256
153 x 32 x 256 =29376 Blocks Free (Commodore DOS Blocks)  BAM/FAT steals 214 Blocks, so the user is left with 29,162 Blocks free on a Newly Formatted Disk.

# Describe the issue
Using raSCSI, I Created a SASI 10MB , IMAGE.HDF with Block Size: 256 bytes, but it does not work with my hardware. So I tired plugging in a real SCSI Hard Drive to my CBM D9090 SASI Controller and it almost works. So I think this SASI device is a lot closer to SCSI in terms of compatibility.

I Cant create a 10MB , IMAGE.HDS with Block Size: 256 bytes
I Created a 10MB , IMAGE.HDF with Block Size: 256 bytes, and then renamed its Extension to IMAGE.HDS, but when I use the Web interface and click the INFO button, it reports:
Product: SCSI HD 10 MB
Revision: 2111
Block Size: 512 bytes

Is there a way to Force raSCSI to allow 256 bytes SCSI HD Image?

uweseimet, 2022-01-15:
@CBMD9090 No, SCSI drives do not support 256 physical bytes per sector. This is only possible with SASI drives, i.e. .hdf is the correct extension. Renaming from .hdf to .hds will not work.
In case of issues with emulated SASI drives you should add a rascsi log on trace level. This may help somebody who is familiar with SASI drives to further analyze your issue.

uweseimet, 2022-01-30:
@CBMD9090 I would like to remind you to add a log on trace level. Without a log it's very unlikely that somebody will ever be able to work on this ticket.

uweseimet, 2022-08-19:
Closing this ticker because a log is still missing. The user appears to have lost interest, and support for 256 bytes per sector media is out of scope anyway.

IgorPetrovich, 2023-10-24:
How to do, what new, empty HDD (.HDS), which i create in \ by use emulators can be visible and usable in editdisk (Disk Explorer)? For work with it...
Need special programs for formating HDD ( .HDS ) before use it or what? (Then which programs?
Why emulators have option "Do logical formatting" only for HDD ( .HDF ), and do not have for HDD ( .HDS ) ?

Any ideas, who have information about it?
How creators of popular in internet archives  " X68000 " ; "X68000V4" - " X68000_V4.HDS ", with many games in it on HDD ( .HDS ) , have sucesfull with thsi task? WHat they used for it?

Btw, editdisk (Disk Explorer) opened their X68000_V4.HDS...
My new created by me in Emulators of Sharp x68000 empty HDD ( .HDS ) - no... :(
Any ideas, information, TIP's, Hints?
Need your help, guys... (  Need your information, TIP's, Hints, Tutorials or Lessons )

I want to know, understand, and use HDD ( .HDS ) for - tests, and because this can be have huge sizes of space (Even in Gbs ), much more than  in .HDF ( Which limited just in 40 Mb. )
But, sies not main reason, just want understand - how use .HDS?!
This main, reason, and can't do this task only by myself need your help, who have knows about it and expirence with work with this...

I just know, whta it is possible ( On example with X68000_V4.HDS by developers of this ), just not know how...
Need your help, guys...

IgorPetrovich, 2023-10-28:
After time i found solved on question 1, about how make HDD ( .HDS )
All sucesfully done by this method, which i was do, and typed full information, and guide \ tutorial for someone else who also will be need this ( In future maybe or right now )...:
What i was do step by step for make HDD ( .HDS )?!
1.: Open Emulator XM6 Pro-68k or xm6_typeg_336_20230523
2.: Chose in options - Tools - Create - Fixed Disc SCSI - HDD ( .HDS ) , with sizes for tests 100 \ 1000 Mb ( In Fact 99 \ 999 Mb)
Choose Sizes ( Capacity )
Other Options:
Options Must Be On "Attached to interface." And "Replace First Drive."
Press "OK"
Checking What In Options Of Emulator, In Option SCSI - SCSI Interface - Internal - SCSI Discs ( via SCSI Interface ) - Drives ( 1 ) - ID ( 0 ) - SCSI-HD Image File ( .HDS )
3.: After created HDD ( .HDS ), i opened Emulator XM6 Pro-68k \ xm6_typeg_336_20230523 , Options - Floppy Drive #0 - MasterDisk_V3
4.: In DOS , in first i typed Command "FORMAT"
5.: Chosed "SCSI Devices" - Enter - "Hard Disc" - Enter - "Initalise" - Enter ( Y ) - "Create" - Enter - "Size"- Enter - Chosed Sizes ( 99 Mb ), by Typed this in window ( In Down Of The Screen ) - Enter -"Start" - Enter - "Create new partition" - "Y" , and got this results in end:
https://i.ibb.co/M2pdx89/44444444.png
6.: "End" - Enter.
7.: Do you want to reset? Most changes to the Partitions need it... Chosed - "Reset" ( By Press "Y" )
Done!
HDD Disc, with format .HDS - already created, formatted, can be readable now, now must be visible( In Programs \ Utilities \ In Emulators ), and ready to work ( For example in Disc Explorer ) .
P.S.:
I really like to write a lot and in detail, describing each point in detail... :)

Closed 2022-08-19.

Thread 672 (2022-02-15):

Electrical short between DB25 connector and PCB through-holes?

marciot, 2022-02-15:
# Info

- Which version of Pi are you using: N/A
- Which github revision of software: N/A
- Which board version: Self-assembled kit FULLSPEC 2.4a
- Which computer is the RaSCSI connected to: N/A

# Describe the issue

I had a RaSCSI that was working fine for many months, but recently the power light would turn off occasionally and the board would stop working. Flexing the board would cause it to come on again. I eventually figured that whatever was going on was happening on the DB50 side. I attempted to reflow all the solder joints and did this not help. Eventually, it occurred to me that there might be a short between the DB50 itself and the through-holes right underneath it. I shimmed a strip of paper between the DB50 and the PCB and the problem has gone away.

I am reporting this to ask whether anyone else has seen this issue. I don't know if all boards have those through-holes under the DB50, as the one pictured in the assembly instruction do not. I also do not know if there is anything electrically conductive underneath that DB50. I seem to recall not, but considering the piece of paper solved the problem I have no other explanation.

marciot, 2022-02-17:
@akuker: Yup, that’s what I meant (sorry, didn’t count the pins). Anyhow, it seems like the underside of the connector is plastic except at the metal end, so I’m not exactly sure why this is causing a problem, especially since it appears everything on the PCB at that end is ground. It could be something in particular about my build, for all I know. But inserting a piece of paper there did solve the issue for me so I thought I would mention it.

marciot, 2022-02-17:
@akuker: Well, I suppose the PCB appears to be ground on the bottom side that is visible. What is on the other side of the PCB? Is there any chance there is a 5V running to the edge of the PCB, nearest the metal edge of the connector? This only started to happen for me after a few months of use, so I wonder if the metal edge scraped away the solder mask on the top side of the board and started to make contact with whatever was underneath.

akuker, 2022-02-17:
You called it!! The 5v line runs right next to that metal connector.
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

Could you try cutting this trace to see if that solves the issue? As long as you're not using the Powerbook connector, there won't be any negative effect.
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

rdmark, 2022-08-19:
Closing since a DIY fix has been identified, and future hardware designs improved to avoid the fail state.

jfredrickson, 2022-09-21:
Just to clarify, does 2.5b fix this?

akuker, 2022-09-22:
I don’t believe so. Unfortunately, we found this issue after the 2.5 boards were already ordered. The 2.6 version will be available next week, which does have the fix for this.

jfredrickson, 2022-09-23:
Is it possible that this bug could have somehow wrecked the SCSI controller on my SPARCstation 10 when the 5V shorted to ground?

I'd been using the RaSCSI successfully for a few months on my Mac and SGI. I recently hooked it up to the Sun and it was working well at first. But due to the physical position of the computer and the RaSCSI, there was more downward pressure on the DB25 connector this time, so I started to get SCSI errors, which led me to discover this issue. Now the Sun cannot access the RaSCSI or even the internal SCSI hard disk. It can see the devices, but I get bus parity errors anytime I try to do something. So I'm worried this caused permanent damage. :(

Closed 2022-08-19.

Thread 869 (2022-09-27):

Make rascsi.cpp more granular and better testable

uweseimet, 2022-09-27:
rascsi.cpp is too big and deals with a lot of unrelated things. The code shall be split into specialized classes, which can at least partially be tested with unit tests. Candidates are:

- RascsiService (thread handling)
- RascsiExecutor (command execution)

uweseimet, 2022-09-29:
@rdmark These and other changes are available in the feature_more_unit_tests branch, which is based on the feature_memory_management branch. For the latter there is already a PR, which I hope will be reviewed soon. Right after feature_memory_management has been approved I intend to create a PR for feature_more_unit_tests.
feature_more_unit_tests provides unit tests not only for SCSI command implementations, but also for the rascsi/rasctl commands, e.g. for detaching or attaching devices. I have tested this branch with buster and bullseye. If you have some time left it would be great if you could also run some tests with your setup.

rdmark, 2022-09-29:
@uweseimet Let me test your branch with my Macs today. I'll let you know how it goes. Immediately on runtime there was a warning with the latest code about invalid log levels that I haven't seen before:
```$ sudo ./rascsi
SCSI Target Emulator RaSCSI Reloaded version 22.09 --DEVELOPMENT BUILD-- (Sep 29 2022, 10:41:30)
Powered by XM6 TypeG Technology / Copyright (C) 2016-2020 GIMONS
Copyright (C) 2020-2022 Contributors to the RaSCSI Reloaded project
Connect type: FULLSPEC
[2022-09-29 11:44:31.101] [info] Set log level to 'info'
[2022-09-29 11:44:31.105] [warning] Invalid log level ''
[2022-09-29 11:44:31.106] [info] No devices currently attached.
No devices currently attached.
```

uweseimet, 2022-09-29:
@rdmark Thank you for testing. Can you please provide the command line that resulted in the log level warning?
Foy any issue you report I will try to add a unit test.

rdmark, 2022-09-29:
@uweseimet I literally just started rascsi without any parameters. No other clients running that could be sending invalid protobuf commands.

uweseimet, 2022-09-29:
@rdmark Yes, I only noticed that after writing my initial comment. Usually I start rascsi with parameters and the first lines of output have scrolled away, this is why I did not notice this message myself.

uweseimet, 2022-09-29:
@rdmark I fixed the log level issue, but while testing more I stumbled upon a memory corruption issue. I suggest that you do not test any further until I have identified and fixed the problem.

uweseimet, 2022-09-30:
@rdmark Looks as if I have fixed the memory corruption issue. The valgrind tool (memory issue check for C/C++) was very helpful once more.

uweseimet, 2022-09-30:
@rdmark I could easily reproduce this issue and with the latest feature_more_unit_tests branch it should be fixed. In case of issues with sending interface commands trace logs usually don't help much. They are in particular important when it is about issues on the SCSI command/protocol level.

By the way, when there are issues with interface commands it does not matter how long rascsi has already been running. The code for executing commands is independant of the code that deals with the SCSI command handling. The command handling happens in a separate thread, which is waiting for commands to arrive on the socket used for the protobuf interface. As long as this thread does not crash (like in this case) the rest of rascsi simply keeps running.

uweseimet, 2022-10-01:
@rdmark Can you please create a new SonarCloud C++ profile (an inherited one) and disable the rule that says that "using namespace" should not be used in header files? For rascsi this rule is not relevant, but it is reported for most header files. I can suppress it in the code but I would like to avoid suppressing messages in the code.

uweseimet, 2022-10-01:
@rdmark I updated the branch with a more transparent command validation, which up to now was essentially based on legacy code.
In case there are still issues with detaching/inserting etc. one can see quite easily (at least I hope so) how the validation and execution works in this method in rascsi_executor.cpp:

```
bool RascsiExecutor::ProcessCmd(const CommandContext& context,
  const PbDeviceDefinition& pb_device, const PbCommand& command, bool dryRun)
```

rdmark, 2022-10-01:
@uweseimet I updated the C++ Sonar profile to turn off those two code smells. Hopefully less noisy reports moving forward. As for the exclusion filters, the only path that we explicitly exclude right now is src/raspberrypi/tests/* so at a glance I cannot say where the problem lies. Might require a bit more investigation.

uweseimet, 2022-10-01:
@rdmark Thank you. Can you please remove the exclusion for the /tests/ folder? I would like to add this exclusion to the github action, because it can be configured externally. But I might not even want to exclude this folder at all, except for the code coverage.
In general I would like to keep the SonarCloud configuration external as far as possible. (For the two code smells there is no external alternative.)

uweseimet, 2022-10-01:
@rdmark Regarding the files where I would have expected problems, I may simple have been wrong. There definitely are code issues, but probably none SonarCloud would report.

rdmark, 2022-10-01:
> @rdmark Thank you. Can you please remove the exclusion for the /tests/ folder? I would like to add this exclusion to the github action, because it can be configured externally. But I might not even want to exclude this folder at all, except for the code coverage. In general I would like to keep the SonarCloud configuration external as far as possible. (For the two code smells there is no external alternative.)

Is it possible to do that kind of granular exclusion from test coverage in the github action config?
And, you're thinking that running static analysis on the test code can also produce valuable feedback?

uweseimet, 2022-10-01:
@rdmark Yes, you can configure the code in the action with sufficient granulariy. Actually, the setting is the same (same arguments) as in the UI.
Regarding test code analysis, this can be valuable, because it can avoid errors in the test code that might result in a test making a wrong assessment. One can turn it off in the github action any time anyway.

uweseimet, 2022-10-01:
@rdmark By the way, even coverage data can sometimes be useful for tests: If the coverage is not 100% not all tests have been executed, which indicates a problem with the test setup. In the past I already stumbled upon such an issue with Java unit tests not being executed.

rdmark, 2022-10-01:
@uweseimet That makes sense. I deactivated the exclusion rule in Sonar. FYI, we still have a code duplication exclusion in place for src/raspberrypi/test/* (Patterns used to exclude some source files from the duplication detection mechanism.)

uweseimet, 2022-10-01:
@rdmark Thank you. Can you please also disable the duplication exclusion? It can also be configured in the action, and I would also like to see what's reported here.

rdmark, 2022-10-01:
@uweseimet Done

uweseimet, 2022-10-01:
@rdmark Thank you!

uweseimet, 2022-10-04:
@rdmark Regarding my expectation that SonarCloud should still report issues for the old code I think I know the resolution: For branches only issues for new (edited) code are reported. Per default only for the master branch there is a full report. This means that only after the next release (after merging into master) one can see the actual status.
IMO we would profit from having a full analysis also for the develop branch. Can you please make the develop branch a long-living branch? See https://community.sonarsource.com/t/how-to-create-long-living-branches-on-sonarcloud/11386.

uweseimet, 2022-10-04:
@rdmark I just tested this by giving a branch a name starting with "branch-", and indeed more issues are reported than on a non long-living branch with the same code. No issues where I would have expected them, though ;-).
But I noticed that there are still issues in the css/html code which are not related to being compatible with old browsers.

Closed 2022-10-04.

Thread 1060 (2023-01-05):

piscsi should not try to initialize bus on aarch64 platform (and others without board)

uweseimet, 2023-01-05:
develop branch as of 2023-01-05.

On all platforms without a PiSCSI board piscsi should run in client interface mode, just like it currently does on Intel PCs:
```
Note: No PiSCSI hardware support, only client interface calls are supported
```
On aarch64 platforms piscsi terminates with an error instead:
```
[2023-01-05 09:51:54.773] [error] Failed to open /proc/device-tree/model. Are you running as root?
[2023-01-05 09:51:54.773] [error] Exception while trying to initialize GPIO bus. Are you running as root?
Error: Can't initialize bus
>name -a
Linux ora1 5.15.0-1025-oracle #31-Ubuntu SMP Fri Nov 25 17:03:15 UTC 2022 aarch64 aarch64 aarch64 GNU/Linux
```

akuker, 2023-01-23:
Do you have any proposals for how to differentiate between aarch64 on a Mac M1 vs 64-Bit raspberry pi?

uweseimet, 2023-01-24:
The presence of the board should be detected dynamically (e.g by the GPIOBus factory), not based on preprocessor constants. A Pi without a board is not different from a non-Pi platform, i.e. relying on the preprocessor would not help in this case.

akuker, 2023-01-29:
As part of this change, the logic should probably be updated to use something other than the model name from the device tree. User "Spike" on discord reported that his Raspberry Pi 4 reported this:
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

This article describes a reliable way to determine which version of Pi is being used:
https://elinux.org/RPi_HardwareHistory#Board_Revision_History

I think we need to add a command line parameter to override this detection as well. It looks like the revision numbers change without new model numbers.

This would also allow for the "virtual" GPIO bus to be specified, even on a raspberry pi or banana pi.

uweseimet, 2023-09-28:
#1179 addresses this for the aarch64 platform based on the __aarch64__ preprocessor mechanism. This way piscsi now also runs on an aarch64 VM in the Oracle cloud (client interface support only), just like on an Intel PC.

rdmark, 2023-10-30:
For the record, this is another example of making an assumption based on architecture:

https://github.com/PiSCSI/piscsi/blob/2de0aa090a95bdad0523cd3e9b90d757dc2367b7/cpp/devices/scsi_daynaport.cpp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

Not as critical as the bus initialization of course, but I just wanted to mention it.

uweseimet, 2023-10-30:
@rdmark Yes, one would have to grep for 'x86' and update all occurrences.

uweseimet, 2023-11-05:
Fixed as port of https://github.com/PiSCSI/piscsi/issues/1295.
```
>uname -a
Linux ora1 5.15.0-1046-oracle #52-Ubuntu SMP Mon Oct 16 09:55:50 UTC 2023 aarch64 aarch64 aarch64 GNU/Linux
>./bin/fullspec/piscsi
SCSI Target Emulator PiSCSI (Backend Service)
Version 23.10 --DEVELOPMENT BUILD--  (Nov  5 2023 16:50:05)
Powered by XM6 TypeG Technology / Copyright (C) 2016-2020 GIMONS
Copyright (C) 2020-2023 Contributors to the PiSCSI project
Connection type: FULLSPEC
[2023-11-05 17:08:23.387] [info] Set log level to 'info'
[2023-11-05 17:08:23.387] [info] Detected unknown platform
[2023-11-05 17:08:23.387] [info] Cleared reserved ID(s)
[2023-11-05 17:08:23.387] [info] No devices currently attached.
No devices currently attached.
Note: No PiSCSI hardware support, only client interface calls are supported
```

Closed 2023-11-05.

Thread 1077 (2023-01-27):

How to properly PHYSICALLY connect a RaSCSI Reloaded board to a Pi to a Macintosh II?

MarcTremblay1981, 2023-01-27:
Hi, first time poster and PiSCSI user here!

- Which version of Pi are you using: Pi Zero W v1.1
- Which github revision of software: PiSCSI 22.12.1
- Which board version: RaSCSI Reloaded Zero v1.0 FULLSPEC
- Which computer is the PiSCSI connected to: Macintosh II (but not yet)

I bought 2 new, pre-assembled RaSCSI Reloaded boards from a seller on eBay and he did not include ANY documentation or install instructions.  I found this GitHub and followed the compile instructions and successfully installed PiSCSI on the Pi Zero W and everything SEEMINGLY works.  I can connect to the PiSCSI Control Page in my web browser and upload, expand and attach devices to the virtual SCSI chain.  All the software side of it, I got it working without any issue.

What bothers me is I don't understand how to properly attach the RaSCSI Reloaded to the Pi, and then the assembly to the Macintosh II to actually make it work.  I had a couple basic questions:

A) Do I have to connect an USB power lead to the RaSCSI Reloaded board? (see Ref-1)
B) Do I have to connect an USB power lead to the Pi Zero W? (see Ref-2)
C) Does the SCSI port on the RaSCSI need to be plugged in the Mac for the Pi to turn on? (see Ref-3)
D) What is the proper orientation of the GPIO hat? (see Ref-4 and Ref-5) Note: According to the GND silk on the RaSCSI, it should be as shown on Ref-4, please correct me if I'm mistaken)
E) Are both jumper pads supposed to be soldered on the back of the RaSCSI? (see Ref-6)

- When I power on the Pi *WITHOUT* the RaSCSI plugged in at all, everything works, the Pi boots up and the PiSCSI Control Page shows up in my web browser after a minute.
- When I power on only the Pi *WITH* the RaSCSI plugged in the Pi, then the Pi does not turn on, no LED at all on any of the two boards.
- When I power on only the RaSCSI  *WITH* Pi plugged in, then the 5V LED is solid on the RaSCSI but the Pi does not turn on.
- When I power both boards, the 5V LED is solid on the RaSCSI but the Pi does not turn on and it makes a high pitch buzzing sound.

Thank you so much to anyone who can help me figure out how to properly connect this device.  I don't understand how there seemingly is no connection diagram anywhere for this device.  I think this would really help beginners like me at least connect the PiSCSI device properly and get started.

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

akuker, 2023-01-27:
> A) Do I have to connect an USB power lead to the RaSCSI Reloaded board? (see Ref-1)

You can connect the power to EITHER the PiSCSI (RaSCSI Reloaded)  OR the Raspberry Pi Zero. The port on the PiSCSI is intended to just be for convenience. When you assemble the PiSCSI Zero with the Pi on top, the SCSI connector will block the power connector.

> B) Do I have to connect an USB power lead to the Pi Zero W? (see Ref-2)

Either port works. But NOT BOTH

> C) Does the SCSI port on the RaSCSI need to be plugged in the Mac for the Pi to turn on? (see Ref-3)

No. The PiSCSI should function stand-alone when power is applied

> D) What is the proper orientation of the GPIO hat? (see Ref-4 and Ref-5) Note: According to the GND silk on the RaSCSI, it should be as shown on Ref-4, please correct me if I'm mistaken)

The PiSCSI/RaSCSI you received is in the "Alternate" configuration on this page: https://github.com/PiSCSI/piscsi/wiki/PiSCSI-Zero-Assembly

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

> E) Are both jumper pads supposed to be soldered on the back of the RaSCSI? (see Ref-6)

It depends on how you're using your PiSCSI. If you're using the PiSCSI Zero, 99.9% of the time you want the term enb pads to be bridged (enabling termination).  Your picture # 6 matches having termination enabled.

The general goal is that the last device on each end of the scsi bus should be terminated. With the PiSCSI Zero, there is only one connector, so it has to be at the end of the chain.

Page 49 of this doc has a little more information: https://vintageapple.org/macmanuals/pdf/Power_Macintosh_Users_Guide_1995.pdf
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

With the jumper bridged, its enables termination. With the jumpers cut (disconnected), termination is disabled

I hope this helps!!

MarcTremblay1981, 2023-01-27:
I literally just discovered one very, very important detail that I could not find anywhere except by taking a much more attentive look to the seller's pictures: It turns out that the GPIO header has to be soldered TO THE BACK of the Pi, not to the front (standard).  This sounds like a very basic thing to consider, but I did not pay attention to the pictures enough and just assumed that the GPIO header was standard when it's in fact backwards.

akuker, 2023-01-27:
You are correct!

rdmark, 2023-01-29:
Since this issue seems to be incorrectly assembled hardware, let us close it for now.

Closed 2023-01-29.

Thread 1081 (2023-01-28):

piscsi doesn't gracefully handle bad (I think?) images

vvuk, 2023-01-28:
# Info

- Which version of Pi are you using: Pi Zero W
- Which github revision of software:  Dec 2022
- Which board version: 4.4
- Which computer is the PiSCSI connected to: Sparcstation 2

I've got an `.iso` that I don't think is actually a valid ISO -- there's some header junk that doesn't look right.  Trying to mount it via the web UI results in an Internal Server Error.  Doing it on the command line results in `Error: Invalid protobuf message header`.

Would be nice if something nicer was reported here.  (Still TBD whether it's a bad image or not, but some error would help me figure that out too :) )

rdmark, 2023-01-28:
@vvuk Can you please share the iso image in question with us?

vvuk, 2023-01-28:
Yep -- should be this one: https://fsck.technology/software/Sun%20Microsystems/SunOS%20Install%20Media/SunOS%204.1.4%20SPARC%20%28CD%29/sunos_4.1.4_install.iso

rdmark, 2023-01-28:
Thanks! This is the actual error message:

```
$ sudo piscsi -ID0 sunos_4.1.4_install.iso
SCSI Target Emulator PiSCSI (Backend Service)
Version 22.12 --DEVELOPMENT BUILD--  (Dec  7 2022 11:36:33)
Powered by XM6 TypeG Technology / Copyright (C) 2016-2020 GIMONS
Copyright (C) 2020-2022 Contributors to the PiSCSI project
Connection type: FULLSPEC
[2023-01-27 19:23:42.093] [info] Set log level to 'info'
[2023-01-27 19:23:42.093] [info] Detected device Raspberry Pi 2/3
[2023-01-27 19:23:42.104] [info] Validating: operation=ATTACH, device id=0, lun=0, type=UNDEFINED, device params='file=sunos_4.1.4_install.iso', vendor='', product='', revision='', block size=0
terminate called after throwing an instance of 'io_exception'
  what():  Raw ISO CD-ROM file size must be a multiple of 2536 bytes but is 378178080 bytes
Aborted
```

uweseimet, 2023-01-28:
The image size is wrong, just as the error message says. But I think we can make this a warning, see https://github.com/PiSCSI/piscsi/pull/1084.

vvuk, 2023-01-28:
Right, the issue is that error message doesn't show up in the web ui, or via scsictl. It doesn't get passed through the protocol. In both of those you just get a generic hard error.

uweseimet, 2023-01-28:
The error message is not propagated to the client (e.g. web UI,  app or scsictl) because the piscsi process terminates. With the fix_issue_1081 feature branch and the related PR this should be resolved. There is only a warning now, because the image does not necesarily have to be rejected, because except for the excess bytes it may contain valid data. That's the same behavior we already have for hard disk images which are not multiples of the physical sector size: The excess bytes are ignored.

uweseimet, 2023-01-28:
@vvuk The fix has been merged into the develop branch. Can you please test whether it works for you?

rdmark, 2023-01-28:
I can confirm that piscsi doesn't abort anymore, and throws a warning log message instead.

uweseimet, 2023-01-28:
@rdmark Sounds good. I am going to close this ticket, because I do not expect @vvuk to still have an issue.

vvuk, 2023-01-28:
Thank you!  I'll confirm when I get a chance -- I'm currently juggling piscsi, scsi2sd, and bluescsi on various computers, need to get the piscsi back in order :)

Closed 2023-01-28.

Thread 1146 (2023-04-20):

INQUIRY Product string too long for image size >9999MiB

rdmark, 2023-04-20:
We generate too long a generic INQUIRY Product string for image sizes larger than 9999MiB

```
Apr 19 18:19:28 rasp32 PISCSI[2604]: [2023-04-19 18:19:28.057] [info] Validating: operation=ATTACH, command params='locale=en', 'token=???', device id=6, lun=0, type=SCHD, device params='file=10000.hds', vendor='', product='', revision='', block size=0
Apr 19 18:19:28 rasp32 PISCSI[2604]: terminate called after throwing an instance of 'std::invalid_argument'
Apr 19 18:19:28 rasp32 PISCSI[2604]:   what():  Product 'SCSI HD 10000 MiB' must be between 1 and 16 characters
Apr 19 18:19:28 rasp32 systemd[1]: Started Process Core Dump (PID 2660/UID 0).
Apr 19 18:19:28 rasp32 systemd-coredump[2661]: [🡕] Process 2604 (piscsi) of user 0 dumped core.

                                               Stack trace of thread 2606:
                                               #0  0x0000000076900420 __GI_raise (libc.so.6 + 0x2e420)
                                               #1  0x00000000768e9364 __GI_abort (libc.so.6 + 0x17364)
                                               #2  0x0000000076b41f88 _ZN9__gnu_cxx27__verbose_terminate_handlerEv (libstdc++.so.6 + 0x7ff88)
```

rdmark, 2023-04-20:
The capacity part of the string is generated in https://github.com/PiSCSI/piscsi/blob/8dd5071122b31fd0418f67c3816b4f086bbe88c2/cpp/devices/scsihd.cpp#L34

What seems to be the problem is that the 10 GB conditional checks against 1 TB (1'099'511'627'776 bytes). I think the correct check should be 10,737,418,240 bytes.

rdmark, 2023-04-20:
I think the sweet spot is to display MiB unit up to 9999MiB, then switch to GB from 10485760000 bytes onwards (10,000MiB).

rdmark, 2023-04-20:
PR in https://github.com/PiSCSI/piscsi/pull/1147

rdmark, 2023-04-20:
This issue would still occur with >9TB image files, but as per Eric: `2tb is the biggest scsi-2 32bit lba can address`

Closed 2023-04-20.

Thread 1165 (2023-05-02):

Hardware version "akuker 2.7" runs transceiver out of spec with Vcc=3.3V

ManuTester, 2023-05-02:
Reviewing the schematic of the hardware version "akuker 2.7",
I found that the 74LS641 is now getting only 3.3V supply voltage.
According to the spec, the minimum voltage is 4.75V.
Has this design been fully tested?
I don't think this will work in all cases, the chip is running completely out of spec,
and there is - to my knowledge - no 74LVC641 or so to replace it.

The outputs are open-collector so not much power is drawn from the Vcc anyway.

Also 10uF caps have been added, one for each transceiver. One 10uF cap per voltage probably won't harm (general buffering of supply, put near pi connector), but what's desperately needed here are blocking/bypass caps, 100nF per chip, no more, no less. You put them as close as possible to the chips. 10uF caps do not work as bypass capacitors!

hemulen242, 2023-05-16:
Can this be confirmed as bug, or will these 74LS641 transceivers run on +3V3 ?

pascalsavigny, 2023-06-11:
Hello, interesting point. Can anyone confirm if it's ok or not ? Are we really out of spec ?
Thanks in advance.
I'd like to place an order for the 2.7 revision....

akuker, 2023-06-20:
> Reviewing the schematic of the hardware version "akuker 2.7", I found that the 74LS641 is now getting only 3.3V supply voltage.
> According to the spec, the minimum voltage is 4.75V.
Good catch @ManuTester . We are running the transceivers outside of the datasheet limits.

> Has this design been fully tested?
Yes, I've been testing with a few boards and haven't run into any issues.

> I don't think this will work in all cases, the chip is running completely out of spec, and there is - to my knowledge - no 74LVC641 or so to replace it.

I did quite a bit of testing with my Macintosh SE/30, but it is possible that some chips may behave differently. Different lots of parts may have different characteristics. For the ones that I'm shipping on Tindie, I'm testing them out and haven't heard any complaints from the ones I've shipped out.

> Also 10uF caps have been added, one for each transceiver. One 10uF cap per voltage probably won't harm (general buffering of supply, put near pi connector), but what's desperately needed here are blocking/bypass caps, 100nF per chip, no more, no less. You put them as close as possible to the chips. 10uF caps do not work as bypass capacitors!

Acknowledged. I'll make this update to the production files in the next few weeks to change the values. Proposed replacement:
https://jlcpcb.com/partdetail/Fojan-FCC0402N101J500AT/C5137573

akuker, 2023-06-20:
> Can this be confirmed as a bug,

Bug? Technically, yes.

> or will these 74LS641 transceivers run on +3V3 ?

I haven't had any issues running on 3.3v, but your mileage may vary. Since its being used outside of spec, it is possible that some chips may work, others may not.

akuker, 2023-06-20:
If anyone has any boards that you're having issues with, please comment here or reach out to me. I agree we are using the part outside of its specification which is not a good idea. I'd like to collect some data to see if folks are having issues. I've tested a hundred or so and haven't seen issues. BUT, it could be that how I'm testing them is tolerant of flakey signals.

uweseimet, 2023-06-20:
I'm not a hardware expert, but nevertheless I would like to comment. IMO running hardware out of spec is not a good idea. Users pay money for the board. If you buy a Pi and a board and then it turns out that the board does not work because some parts are run out of spec this definitely would not do the PiSCSI project any favor. Why taking such a risk?
Just my two cents.

ManuTester, 2023-06-20:
I think @akuker intended to reduce power consumption that's why he went to 3.3V, but:
The 74LS641 has open collector output, that means only very little power ist drawn from VCC, I don't think much power can be saved this way. It should be changed back. Sure, I believe it works and if you have such a board and it works, fine you got no problem. Underrunning the chip won't harm it, but the input threshold levels on the 5v input signals won't be correct and it may also draw more current from there.
I looked at the capacitor you chose as bypass cap, that one is 100p not 100n! Also why choose such a small one (0402) the 0805 are much easier to handle/solder by hand.

uweseimet, 2023-10-02:
What are going to be the next steps in order to resolve this ticket?

akuker, 2023-10-14:
Note: I have shut down my tindie store indefinitely. I don't think there is anything that needs to be done with this ticket, unless someone else is going to make hardware modifications. Therefore, I'm closing it.

Closed 2023-10-14.

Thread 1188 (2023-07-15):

Drives not detected

hydrohs, 2023-07-15:
# Info

- Which version of Pi are you using: 3B
- Which github revision of software: 23.04.01
- Which board version: 2.5b
- Which computer is the PiSCSI connected to: Macintosh SE and Power Macintosh 6500

# Describe the issue
I can’t get either of my Macs to detect disks via the PiSCSI. SCSIProbe on my Mac SE says the bus is not terminated if I attach a drive (if the PiSCSI is physically connected, but no drives are attached it’s fine) with the dip switches in either configuration. On the Power Mac, doing a scan with Lido just gives bus errors with a drive attached. Since it appeared to be a termination issue I checked the connections with my multimeter and everything seems to be going where it’s supposed to.

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

rdmark, 2023-07-15:
Did you go through the steps in https://github.com/PiSCSI/piscsi/wiki/Troubleshooting ?

Do other SCSI devices work with the same chain? There's always the chance that there are hardware issues, oxidized contacts, poor SCSI cables, etc.

Have you read through https://github.com/PiSCSI/piscsi/wiki/Drive-Setup and made sure you're using good images?

hydrohs, 2023-07-16:
I totally missed the troubleshooting page, thank you.

I don't have a loopback cable, though I think I have what I need to make one. However checking voltages with my multimeter; D5 is stuck low and D6 is stuck high, everything else is good. I see on the schematic both of those go through IC2, checking again for continuity from the IC to the GPIO pins everything seems connected. Is it just a bad chip, then?

akuker, 2023-07-18:
Its possible. I've had a few bad chips, but not many. Depending upon how good you are with a solder rework station, you could swap IC1 and IC2. IC2 is only used for the data parity bit (on this version of the board). So, if your host ignores parity (Macintosh's do), that might be a solution. Or, at least narrow it down to a specific part.

rdmark, 2023-09-25:
@hydrohs were you able to get to a working piscsi setup?

hydrohs, 2023-10-16:
Sorry, I have not been able to get it working, just not able to get the parts for testing so I will mark this closed. Appreciate the help.

uweseimet, 2023-10-16:
@hydrohs Thank you for your swift response. Just re-open the ticket at some time in the future if needed.

Closed 2023-10-16.

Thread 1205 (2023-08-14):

Help identify GPIO pin stopping piscsi from working?

durosity, 2023-08-14:
Howdy!

I have a couple of piSCSI units and a Pi 3a and Pi Zero W.  Both the piscsi boards work fine with the Zero, and used to work with the 3a until I had to replace the header pins due to damage.  Since then the piscsi will power up when used with the 3a but the host device won't see any scsi devices, so clearly I've broken one or more of the pin connections.

The problem is I'm struggling to identify which one is causing it.  I've reflowed the solder connections and checked the continuity on the ones that I can see the traces for, but that's only a handful of pins.

Are there any logs that I could see on the pi that'd suggest where the problem is?

uweseimet, 2023-09-25:
I just stumbled upon this issue and wonder why it has not been resolved yet. There are no such logs, and I doubt that it is technically possible to have any kind of logging for such an issue.

Closed 2023-09-25.

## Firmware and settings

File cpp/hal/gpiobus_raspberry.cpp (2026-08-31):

//---------------------------------------------------------------------------
//
//	SCSI Target Emulator PiSCSI
//	for Raspberry Pi
//
//	Powered by XM6 TypeG Technology.
//	Copyright (C) 2016-2020 GIMONS
//
//	[ GPIO-SCSI bus ]
//
//  Raspberry Pi 4:
//     https://datasheets.raspberrypi.com/bcm2711/bcm2711-peripherals.pdf
//  Raspberry Pi Zero:
//     https://datasheets.raspberrypi.com/bcm2835/bcm2835-peripherals.pdf
//
//---------------------------------------------------------------------------

#include <spdlog/spdlog.h>
#include "hal/gpiobus_raspberry.h"
#include "hal/gpiobus.h"
#include "hal/systimer.h"
#include <fcntl.h>
#include <map>
#include <cstring>
#ifdef __linux__
#include <sys/epoll.h>
#endif
#include <sys/ioctl.h>
#include <sys/mman.h>
#include <sys/time.h>

//---------------------------------------------------------------------------
//
//	imported from bcm_host.c
//
//---------------------------------------------------------------------------
uint32_t GPIOBUS_Raspberry::get_dt_ranges(const char *filename, uint32_t offset)
{
    GPIO_FUNCTION_TRACE
    uint32_t address = ~0;
    if (FILE *fp = fopen(filename, "rb"); fp) {
        fseek(fp, offset, SEEK_SET);
        if (array<uint8_t, 4> buf; fread(buf.data(), 1, buf.size(), fp) == buf.size()) {
            address = (int)buf[0] << 24 | (int)buf[1] << 16 | (int)buf[2] << 8 | (int)buf[3] << 0;
        }
        fclose(fp);
    }
    return address;
}

uint32_t GPIOBUS_Raspberry::bcm_host_get_peripheral_address()
{
    GPIO_FUNCTION_TRACE
#ifdef __linux__
    uint32_t address = get_dt_ranges("/proc/device-tree/soc/ranges", 4);
    if (address == 0) {
        address = get_dt_ranges("/proc/device-tree/soc/ranges", 8);
    }
    address = (address == (uint32_t)~0) ? 0x20000000 : address;
    return address;
#else
    return 0;
#endif
}

bool GPIOBUS_Raspberry::Init(mode_e mode)
{
    GPIOBUS::Init(mode);
    MakeSignalTable();

#if !defined(__linux__) || defined(__x86_64__) || defined(__X86__)
    (void)baseaddr;
    level = new uint32_t();
    return true;
#else
    int i;
#ifdef USE_SEL_EVENT_ENABLE
    epoll_event ev = {};
#endif

    // Get the base address
    baseaddr = (uint32_t)bcm_host_get_peripheral_address();

    // Open /dev/mem
    int fd = open("/dev/mem", O_RDWR | O_SYNC);
    if (fd == -1) {
        spdlog::error("Error: Unable to open /dev/mem. Are you running as root?");
        return false;
    }

    // Map peripheral region memory
    void *map = mmap(NULL, 0x1000100, PROT_READ | PROT_WRITE, MAP_SHARED, fd, baseaddr);
    if (map == MAP_FAILED) {
        spdlog::error("Error: Unable to map memory: "+ string(strerror(errno)));
        close(fd);
        return false;
    }

    // Determine the type of raspberry pi from the base address
    if (baseaddr == 0xfe000000) {
        rpitype = 4;
    } else if (baseaddr == 0x3f000000) {
        rpitype = 2;
    } else {
        rpitype = 1;
    }

    // GPIO
    gpio = (uint32_t *)map;
    gpio += GPIO_OFFSET / sizeof(uint32_t);
    level = &gpio[GPIO_LEV_0];

    // PADS
    pads = (uint32_t *)map;
    pads += PADS_OFFSET / sizeof(uint32_t);

    // System timer
    SysTimer::Init();

    // Interrupt controller
    irpctl = (uint32_t *)map;
    irpctl += IRPT_OFFSET / sizeof(uint32_t);

    // Quad-A7 control
    qa7regs = (uint32_t *)map;
    qa7regs += QA7_OFFSET / sizeof(uint32_t);

    // Map GIC memory
    if (rpitype == 4) {
        map = mmap(NULL, 8192, PROT_READ | PROT_WRITE, MAP_SHARED, fd, ARM_GICD_BASE);
        if (map == MAP_FAILED) {
            close(fd);
            return false;
        }
        gicd = (uint32_t *)map;
        gicc = (uint32_t *)map;
        gicc += (ARM_GICC_BASE - ARM_GICD_BASE) / sizeof(uint32_t);
    } else {
        gicd = NULL;
        gicc = NULL;
    }
    close(fd);

    // Set Drive Strength to 16mA
    DrvConfig(7);

    // All supported profiles use SCSI logical signal control.
    const int pullmode = GPIO_PULLNONE;

    // Initialize all signals
    for (i = 0; SignalTable[i] >= 0; i++) {
        int j = SignalTable[i];
        PinSetSignal(j, OFF);
        PinConfig(j, GPIO_INPUT);
        PullConfig(j, pullmode);
    }

    // Set control signals
    PinSetSignal(PIN_ACT, OFF);
    PinSetSignal(PIN_TAD, OFF);
    PinSetSignal(PIN_IND, OFF);
    PinSetSignal(PIN_DTD, OFF);
    PinConfig(PIN_ACT, GPIO_OUTPUT);
    PinConfig(PIN_TAD, GPIO_OUTPUT);
    PinConfig(PIN_IND, GPIO_OUTPUT);
    PinConfig(PIN_DTD, GPIO_OUTPUT);

    // Set the ENABLE signal
    // This is used to show that the application is running
    PinSetSignal(PIN_ENB, ENB_OFF);
    PinConfig(PIN_ENB, GPIO_OUTPUT);

    // GPIO Function Select (GPFSEL) registers backup
    gpfsel[0] = gpio[GPIO_FSEL_0];
    gpfsel[1] = gpio[GPIO_FSEL_1];
    gpfsel[2] = gpio[GPIO_FSEL_2];
    gpfsel[3] = gpio[GPIO_FSEL_3];
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

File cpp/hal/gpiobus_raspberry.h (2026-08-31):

//---------------------------------------------------------------------------
//
//	SCSI Target Emulator PiSCSI
//	for Raspberry Pi
//
//	Powered by XM6 TypeG Technology.
//	Copyright (C) 2016-2020 GIMONS
//	[ GPIO-SCSI bus ]
//
//---------------------------------------------------------------------------

#pragma once

#include "hal/data_sample_raspberry.h"
#include "hal/gpiobus.h"
#include "shared/scsi.h"
#include <map>

//---------------------------------------------------------------------------
//
//	SCSI signal pin assignment setting
//	  GPIO pin mapping table for SCSI signals.
//	  PIN_DT0～PIN_SEL
//
//---------------------------------------------------------------------------

#define ALL_SCSI_PINS                                                                                      \
    ((1 << PIN_DT0) | (1 << PIN_DT1) | (1 << PIN_DT2) | (1 << PIN_DT3) | (1 << PIN_DT4) | (1 << PIN_DT5) | \
     (1 << PIN_DT6) | (1 << PIN_DT7) | (1 << PIN_DP) | (1 << PIN_ATN) | (1 << PIN_RST) | (1 << PIN_ACK) |  \
     (1 << PIN_REQ) | (1 << PIN_MSG) | (1 << PIN_CD) | (1 << PIN_IO) | (1 << PIN_BSY) | (1 << PIN_SEL))

#define GPIO_INEDGE ((1 << PIN_BSY) | (1 << PIN_SEL) | (1 << PIN_ATN) | (1 << PIN_ACK) | (1 << PIN_RST))

#define GPIO_MCI ((1 << PIN_MSG) | (1 << PIN_CD) | (1 << PIN_IO))

//---------------------------------------------------------------------------
//
//	Constant declarations (GIC)
//
//---------------------------------------------------------------------------
const static uint32_t ARM_GICD_BASE = 0xFF841000;
const static uint32_t ARM_GICC_BASE = 0xFF842000;
const static uint32_t ARM_GIC_END   = 0xFF847FFF;
const static int GICD_CTLR          = 0x000;
const static int GICD_IGROUPR0      = 0x020;
const static int GICD_ISENABLER0    = 0x040;
const static int GICD_ICENABLER0    = 0x060;
const static int GICD_ISPENDR0      = 0x080;
const static int GICD_ICPENDR0      = 0x0A0;
const static int GICD_ISACTIVER0    = 0x0C0;
const static int GICD_ICACTIVER0    = 0x0E0;
const static int GICD_IPRIORITYR0   = 0x100;
const static int GICD_ITARGETSR0    = 0x200;
const static int GICD_ICFGR0        = 0x300;
const static int GICD_SGIR          = 0x3C0;
const static int GICC_CTLR          = 0x000;
const static int GICC_PMR           = 0x001;
const static int GICC_IAR           = 0x003;
const static int GICC_EOIR          = 0x004;

//---------------------------------------------------------------------------
//
//	Constant declarations (GIC IRQ)
//
//---------------------------------------------------------------------------
const static int GIC_IRQLOCAL0 = (16 + 14);
const static int GIC_GPIO_IRQ  = (32 + 116); // GPIO3

//---------------------------------------------------------------------------
//
//	Class definition
//
//---------------------------------------------------------------------------
class GPIOBUS_Raspberry : public GPIOBUS
{
  public:
    GPIOBUS_Raspberry()           = default;
    ~GPIOBUS_Raspberry() override = default;
    bool Init(mode_e mode = mode_e::TARGET) override;

    void Reset() override;
    void Cleanup() override;

    //	Bus signal acquisition
    uint32_t Acquire() override;

    // Set ENB signal
    void SetENB(bool ast) override;

    // Get BSY signal
    bool GetBSY() const override;
    // Set BSY signal
    void SetBSY(bool ast) override;

    // Get SEL signal
    bool GetSEL() const override;
    // Set SEL signal
    void SetSEL(bool ast) override;

    // Get ATN signal
    bool GetATN() const override;
    // Set ATN signal
    void SetATN(bool ast) override;

    // Get ACK signal
    bool GetACK() const override;
    // Set ACK signal
    void SetACK(bool ast) override;

    // Get ACT signal
    bool GetACT() const override;
    // Set ACT signal
    void SetACT(bool ast) override;

    // Get RST signal
    bool GetRST() const override;
    // Set RST signal
    void SetRST(bool ast) override;

    // Get MSG signal
    bool GetMSG() const override;
    // Set MSG signal
    void SetMSG(bool ast) override;

    // Get CD signal
    bool GetCD() const override;
    // Set CD signal
    void SetCD(bool ast) override;

    // Get IO signal
    bool GetIO() override;
    // Set IO signal
    void SetIO(bool ast) override;

    // Get REQ signal
    bool GetREQ() const override;
    // Set REQ signal
    void SetREQ(bool ast) override;

    // Get DAT signal
    uint8_t GetDAT() override;
    // Set DAT signal
    void SetDAT(uint8_t dat) override;

    bool WaitREQ(bool ast) override
    {
        return WaitSignal(PIN_REQ, ast);
    }
    bool WaitACK(bool ast) override
    {
        return WaitSignal(PIN_ACK, ast);
    }
    static uint32_t bcm_host_get_peripheral_address();

    unique_ptr<DataSample> GetSample(uint64_t timestamp) override
    {
        Acquire();
        return make_unique<DataSample_Raspberry>(signals, timestamp);
    }
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

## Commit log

2020-07-05 First round of translating the code comments and error messages to English. Most of the heavy lifting was done by Google translate
    [cfilesystem.h]
2020-07-07 Failed attempt at monitoring the SCSI traffic.
    [gpiobus.cpp]
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2020-07-09 Added some debug code for Issue #2. This will print out a warning when we get an unhandled mode page code, instead of crashing
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2020-07-27 Created conceptual wireframe and generated new php file that sort-of matches the wireframe. Still a work in progress and doesn't do anything useful (yet)
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2020-08-02 Fixed silkscreen for tranceivers
    [rascsi_2p1.kicad_pcb]
2020-08-03 Fixed orientation of termpwr diode. Updated to version "2.1a"
    [rascsi_2p1.kicad_pcb, rascsi_2p1.sch]
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2020-08-07 Updated to allow command handler to run on x86 systems for development purposes. Also fixed warning about using fprintf incorrectly
    [gpiobus.cpp]
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2020-08-09 Reimplement ParseArgs() with getopt()
    The command-line interface is intended to be equivalent. For example,
    consider this command:
    $ rascsi -ID0 zero.hda -ID1 one.hda
    This is no longer two pairs (ID0, zero.hda), (ID1, one.hda), but a
    sequence of commands:
    * -I: next disk is SCSI (not SASI)
    * -D 0: next disk is device 0
    * zero.hda: set up disk
    * -I: next disk is SCSI (not SASI)
    * -D 1: next disk is device 1
    * one.hda: set up disk
    Since SCSI is [now] the default, this could equivalently be:
    $ rascsi -d 0 zero.hda -d 1 one.hda
2020-08-14 Created version 1.6 with issue #10 fixed. Renamed version 1.5 to a better folder name
    [rascsi_din-B_Mask.gbr, rascsi_din-B_Paste.gbr, rascsi_din-B_SilkS.gbr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]
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2020-08-28 These files were moved into the devices folder for issue #16, but weren't cleaned up. Removing the extraneous files.
    [cfilesystem.h]
2020-09-05 Updated makefile to automatically configure systemd and rsyslog (#32)
    * Corrected rascsi service and rsyslog configs. Updated makefile to install these configs
    * Removed systemd service commands. Added a 'help' target that prints information about how to use this Makefile
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2020-09-12 Proposed 2p3 version - Added RPi HAT EEPROM, fixed 3v/5v LED caption, added copper to USB port traces
    [Serial_Eeprom.sch, USB_Conn.sch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]
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2020-09-22 Updated to correct part fields and descriptions. Removed conflicting mouser references
    [USB_Conn.sch, rascsi_2p3.sch, rascsi_2p3_bom_csv_grouped_by_value.csv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]
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2020-10-17 Fix nothing displayed with no images mounted. (#45)
    * Fix nothing displayed with no images mounted.
    This fixes the issue where nothing would show on the display unless an image is mounted.
    * Fixed the indent
    * Fixes not working when image attached issue
    Original commit caused the display not to work when an image was attached. This has now been fixed.
    * Fixed multiple images attached not working
    Forgot to remove testing code that caused multiple image displays to break.
2020-10-19 Issue #7 - implement a scsi monitor function for RaSCSI to log SCSI traffic (#46)
    * #7 Re-merge scsimon functionality with latest master. The old scsimon branch was waaaaay too out of date
    * #7 Re-merge scsimon functionality with latest master. The old scsimon branch was waaaaay too out of date
    * Added libspdlog-dev as a required package
    * Cleanup from master re-base
    * Updated to use GCC version 8, to match the raspberry pi
    [gpiobus.cpp, gpiobus.h]
2020-12-31 New Web Interface (#69)
    * gitignore
    * New Web Interface
    Fixed spacing/tabs in easy install
    Added migration check
    Fix update web not actually updating
    Migrating from https://github.com/erichelgeson/RaSCSI-web
    * Allow user to select multiple types when creating images
    * Show all devices even if nothing is attached.
    * If attaching an iso to a cd device, dont detach, just insert
    * UI feedback and restart rascsi service
    * Check for any non-0 exit code for apache2 detection
    * Pretty/informative 502
    * Add confirms to some actions. Works in netscape 4.7
    * Fix order of params for create_new_image
    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
2021-01-22 Added STEP file and updated symbol and 3d model references to reference the correct gender of parts. Should be no functional change
    [daisy_chain_board.kicad_pcb, daisy_chain_board.sch]
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2021-02-03 Revert "Add Daynaport SCSI/Link Functionality" (#78)
    [gpiobus.h]
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2021-03-08 FIxing code and comment alignment
    going through the various files and putting comments on one line for easier reading.
    [cfilesystem.h]
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2021-04-05 Added short delay after the DaynaPort reports its metadeta during a READ operation
    [gpiobus.cpp, gpiobus.h]
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2021-06-08 RaSCSI hardware version 2.4 (#94)
    * First attempt at adding 2.5 inch drive connector
    * Clean up silkscreen and fix DRC issues
    * additional cleanup. Made Pin 1 of the PB connector square
    * minor tweaks
    * Updates for ordered version
    * Generate step file and schematic pdf
    * First draft of powerbook drive bracket
    * Added side holes and hole for MIPI connector
    * Additional updates to the powerbook 3d printed bracket
    * Moved RaSCSI board 1mm in + lots of cleanup
    * Added optional floppy power connector. As-ordered version 2.4a
    * Added optional floppy power connector. As-ordered version 2.4a
    [Connectors.sch, Serial_Eeprom.sch, USB_Conn.sch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]
2021-06-09 Merge Hw 2p4 to develop (#109)
    * Generated .STEP file for RaSCSI
    * Added STEP file and updated symbol and 3d model references to reference the correct gender of parts. Should be no functional change
    * Added STEP file and updated symbol and 3d model references to reference the correct gender of parts. Should be no functional change
    * Added 3D models and correct footprints for STEP file
    * Merge version 20.12.0 into the master branch (#75)
    * Update README.md
    Added refe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
    [Connectors.sch, Serial_Eeprom.sch, USB_Conn.sch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]
2021-06-23 Fixes for gcc 10.3.0 (#112)
    * Fixes for gcc 10.3.0
    * Fixes for gcc 10.3.0
    * Removed obsolete declaration
    * Changes based on review
    [gpiobus.cpp]
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2021-07-08 Removed useless assertions (#125)
    * Removed useless assertions
    * Finalized removal
    * Pointer was passed instead of integer value
    * Fixed data type issue on 64 bit compile platforms
    * Added missing virtual destructor (gcc warning)
    [cfilesystem.h]
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2021-07-18 protobuf-based rasctl/rascsi command interface (#129)
    * Initial protobuf definition
    * protobuf result message draft
    * Merge with develop branch
    * Makefile generates protobuf-based source files
    * Interface update
    * Fixed typo
    * Fixed typo
    * Updated returning status
    * Serialize return data
    * Use correct descriptor
    * Made interface fields required
    * Deserialize result
    * Serialization update
    * Updated serialization
    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
    [gpiobus.cpp]
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2021-07-20 Feature baremetal removal (#140)
    * Removed all BAREMETAL ifdefs
    * Cleaned up subfolders
    * Fixed regression
    * Re-added underscores
    * Fixed merge conflicts
    * Assume RASCSI is always defined
    * Fixed mege issue
    * Re-added result message
    * Fix typo
    [cfilesystem.h, gpiobus.cpp, gpiobus.h]
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2021-08-08 Feature extended server information (#169)
    * Added additional status data (ejectable, protctable, removable)
    * Assume ejectable == removable
    * Removed obsolete fields
    * Added locked/lockable to interface
    * Code review
    * Logging update
    * The user should be allowed to also write protect hard disk drives
    * Updated error handling
    * Testing
    * INSERT also has to search in the default file folder
    * Added TODO
    * Manpage update
    * Message updates
    * Moved some sanity checks to the server, so that they are run for any client
    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
    [gpiobus.cpp]
2021-08-10 Added PbDevices to PbServerInfo for client convenience (#176)
    * Added device list to server info
    * Updated loggin
    * Added comment
    * Added comment
    * Added comment
    * Deprecate LIST
    * Updated duplicate ID/unit check
    * Updated logging
    * Updated logging
    * Unified error message handling: Errors are now consistently logged
    * REview
    * Added missing field initialization (reported by Eclipse IDE)
    * Added some translations
    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
    [gpiobus.cpp, gpiobus.h]
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2021-09-15 Configurable block size, controller/device cleanup, dispatchers per device, bridge setup (#203)
    * Use foreach
    * Revert "Renaming"
    This reverts commit b0554b9c0a052e282625a4565d429313af2b3cc7.
    * Manpage updates
    * Removed obsolete assertions
    * Replaced QWORD by uint64_t and removed respective typedef
    * Removed LPCSTR typedef
    * Removed LPCTSTR typedef
    * Removed LPTSTR typedef
    * Renamed SCSI command interface classes
    * Renamed xm6.h to rascsi.h
    * Moved interface classes to new interfaces subfolder
    * Added include
    * Fixed compilation issues of 64 bit Ubuntu
    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
    [cfilesystem.h]
2021-09-15 Move to protobuf for the webapp, major overhaul to easyinstall.sh, code comment translations (#229)
    * Making saving and loading config files work with protobuf
    * Formatted the Status column, and fixed the available ID logic
    * Updated handling of removed status for devices without image file support
    * Updated handling of removed status for devices without image file support
    * Better handling of device status
    * Updated parameter handling
    * Updated setting default interfaces
    * Revert "Updated setting default interfaces"
    This reverts commit 210abc775d9a79dd0c6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
    [cfilesystem.h]
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2021-11-14 Code cleanup (#442)
    * Fixed clang warnings
    * Removed obsolete logging
    * Collection usage cleanup
    * Use sorted collections
    * Updated sorting, added comments
    * Improved locality of code
    * Simplified vector initialization
    * Collection usage cleanup
    * Removed useless comments and assertions
    * Removed useless comments, removed code inconsistencies
    * Removed useless comments, renaming
    * Replaced cast by a more explicit logical operation
    * Removed target with hard-coded paths
    * Include file cleanup
    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
    [gpiobus.cpp]
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2021-11-14 Fix daisychain board files (#462)
    * Revert "Added STEP file and updated symbol and 3d model references to reference the correct gender of parts. Should be no functional change"
    This reverts commit 479cc578b885d9d675a35aab40d5217a447c2dfc.
    * Delete rascsi_tester that didn't work
    [Test_Circuit.sch, daisy_chain_board.kicad_pcb, daisy_chain_board.sch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]
2021-11-27 Feature READ/WRITE LONG(10/16) (#481)
    * Partial implementation of READ/WRITE LONG(10)
    * Updated dispatcher table
    * Added READ/LONG(16)
    * Added 16 byte opcode
    * Updated flushing
    * Check start sector
    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
    [gpiobus.cpp]
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2021-12-26 Web Interface i18n (#564)
    * Add flask_babel 2.0.0 to requirements
    * Partial i18n
    * Use current locale for protobuf requests
    * Don't store generated messages.pot in git
    * Internationalize all python code
    * Formatting fixes
    * Partial internationalization of html
    * Iterate on html i18n
    * Completed i18n of code
    * Improve i18n of strings
    * Blurb about i18n in the readme
    * Improve i18n strings
    * Add the compiled messages.mo files to .gitignore
    * Add complete Swedish localization
    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
    [babel.cfg]
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2022-01-07 Output higher-level report from scsimon (#596)
    * Output JSON file for post-processing
    * Debug utility for parsing the SCSI data
    * Prototype app for parsing scsi captures
    * correct arg parsing
    * output html
    * Cleanupt html output
    * Add missing include
    * Allow compilation on non-Linux platforms
    * Refactored scsimon to be in multiple files
    * Refactored away
    * Restructured scsimon into smaller pieces
    * Added ability to read in pre-generated .json file and re-parse it
    * Delete scsiparse.cpp
    * Fix argument parsing and code cleanup
    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
    [gpiobus.cpp]
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2022-02-13 Inheritance hierarchy improvements, reduced dependencies to Disk class (#662)
    * Fixed buster compile-time issue
    * Host services inherit from ModePageDevice
    * Call base class
    * Visibility update
    * Updated includes
    * Updated dispatcher
    * Added TODOs
    * Use namespace instead of class for ScsiDefs
    * Use dispatcher template in order to remove duplicate code
    * Updated all dispatchers
    * Clean up commands
    * Updated template definition
    * Device list must be static
    * Logging updat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
    [gpiobus.cpp, gpiobus.h]
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2022-02-27 Code cleanup, in particular related to MODE SENSE (#699)
    * Replace member functions
    * Fixed TODO
    * Fixed return value
    * CD-ROM mode pages are provided by the CD-ROM implementation
    * MO mode pages are provided by the MO implementation
    * Removed more duplicate code
    * Optimization
    * Updated mode page size handling
    * Addec TODO
    * Started more flexible mode page handling
    * Map mode pages
    * Page 0 must be last
    * Updated size handling
    * Updated map handling
    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
    [gpiobus.h]
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2022-03-03 Hardware Version 2.5 (#720)
    * Added header for external ENB LED
    * test fixture for rascsi
    * test fixture for rascsi
    * Updated to Kicad 6 and modified act LED
    * Regenerated Gerber files to fix drill placement. Added CE logo
    * Regeneraged gerbers
    [Connectors.kicad_sch, USB_Conn.kicad_sch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]
2022-03-03 Control board for managing the RaSCSI configuration (#721)
    * First draft of control board - Issue #382
    * routed signals
    * Fixed up silkscreens and added mousebites
    * Fixed up silkscreens and added mousebites
    * 3d models of encoder and display
    * cleaned up layout
    * cleaned up layout
    * Rename project
    * Remove extraneous files
    * As-ordered version
    * As-ordered version
    * version 1.5 updates
    * Updated to Kicad 6.0
    * Genereated Gerber Files
    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
    [PCA9554APW_118.step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]
2022-03-06 SASI FORMAT opcode fix, SASI segfault fix, added SASI INQUIRY/READ CAPACITY, 512 bytes per sector SASI drives (#724)
    * Fixed opcode
    * Fixed segfault
    * Re-added 0x06 as additional SASI FORMAT opcode
    * Added support of SASI drives with 512 bytes
    * SASI LUN must always be taken from CDB and must be 0 or 1
    * Fixed one more SASI segfault
    * Added enum value for SPC-6
    * Added support for SASI Inquiry
    * Updated SASI LUN check
    * Updated SASI LUN handling
    * Revert "Comment update"
    This reverts commit c6adbde25c2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
    [gpiobus.cpp, gpiobus.h]
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2022-09-03 SASI code removal, error handling update, bug fixes, code cleanup (#806)
    Summary ov most important changes triggered by the SASI code removal:
    - Removed the SASI controller code
    - New controller management. There is a new controller base class AbstractController and a class ControllerManager managing the controller lifecycle. The lifecycle management was removed from rasci.cpp and is covered by unit tests.
    - New device management. The DeviceFactory manages the device lifecycle instead of rascsi.cpp. The new code is covered by unit tests.
    - The lifecycle managment uses C++ collections with variable size instead of arrays with hard-coded sizes.
    - The ScsiController method contains most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
    [cfilesystem.h]
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2022-09-07 Fix simple SonarCloud issues (#834)
    * Fixing SonarCloud issues, first round
    * Fixing SonarCLoud issues, next round
    * Fixing SonarQube issues, next round
    * Replaced empty constructors/destructors with = default;
    * Replaced new
    * Use constants instead of macros
    * Use structured binding declarations
    * Use init statements for if
    * Use string views
    * Use enum class, use using instead of typedef
    * Fixed more SonarCloud warnings
    * Replaced redundant/duplicate types with auto
    * Devlared methods const
    * Memory management update
    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
    [cfilesystem.h]
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2022-09-10 SonarCloud coverage setup, fixed numerous SonarCloud issues (#840)
    * SonarCloud coverage setup, fixed numerous SonarCloud issues
    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
    [cfilesystem.h]
2022-09-10 Breakup GPIOBUS (#843)
    * moved gpiobus
    * moved gpiobus and systimer into hardware abstraction layer
    * split up gpiobus by connection type
    * merge develop changes
    * revert compiler setting change
    * registers working
    * updates
    * updates
    * Revert "updates"
    This reverts commit 0134b810612581893bf6e831ddcd9a2b430a41ed.
    * Revert "updates"
    This reverts commit 4bf0416ab4602614c1a8fbb2fab3d9658f6cddff.
    * Revert "registers working"
    This reverts commit f5ee073eafa7acc83f2aa3badf23552da30d68ed.
    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
    [gpiobus.cpp, gpiobus.h]
2022-09-15 Memory management update, SonarCloud fixes, fix for issue #841 (#842)
    - Memory management updates, more fixed Sonar issues
    * Replaced macros, fixed other sonar issues
    * Added const, replaced enum with a single value by constant
    * Updated object initializations
    * Fixed potential strncpy overflow reported by gcc 8.3
    [cfilesystem.h]
2022-09-21 Cleanup (memory management, STL containers, type safety) based on SonarCloud report (#845)
    * Removed static/global variable
    * No need for ControllerManager as a singleton
    * Updated factory handling
    * Replaced loops
    * Added const
    * Added translations, fixed TODO, simplified operation creation
    * Fixed SonarCloud warnings
    * Replaced void * by BYTE *
    * Added explicit mode_page_datetime struct
    * Unit test updates
    * Use enum classes
    * Upddated file size check
    * Use C++ output formatting
    * Use array for garbage buffer
    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
    [cfilesystem.h]
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2022-09-25 Added unit tests and convenience methods, fixed SonarCloud issues, include file cleanup (#849)
    * Added unit tests, add convenience methods, fixed SonarCloud issues
    * Replaced C-style arrays by C++ arrays
    * Replaced ASSERT
    * Constants cleanup
    * Moved _LARGEFILE64_SOURCE to Makefile, so that os.h is not always needed
    * os.h cleanup
    * Fixed clang++ warnings
    * Split protobuf_util
    * Fixed SonarCloud issues
    * DeviceFactory is not a singleton anymore
    * Replaced macros
    * Removed obsolete interface
    * Replaced DWORD
    * Extracted CDTrack
    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
    [cfilesystem.h]
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2022-10-04 More unit tests, replacement of raw pointers and C arrays, separation of concerns (#878)
    * Updated deletion of controllers
    * Image folder handling cleanup
    * Fixed clang warning
    * Reduced code complexity
    * Updated array handling
    * Initialize device with ID and LUN
    * Use smart pointers
    * Updated memory management
    * Logging updates
    * Split scsi.h
    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
    [cfilesystem.h]
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2022-10-08 Merged FileSupport into Disk, improved granularity, more unit tests, code cleanup (#897)
    * Merged FileSupport into Disk
    * Improved code granularity
    * Made classes previously directly writing to cout testable
    * Added numerous unit tests
    * Fixed minor issues uncovered by unit tests
    * Replaced remaining proprietary data types (WORD/DWORD) except for files in hal/
    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
    [cfilesystem.h]
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2022-10-25 Use C++ filesystem library/iostreams for I/O, added unit tests (#911) (#934)
    * Use C++ filesystem library/iostreams for I/O (issue #911)
    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
    [cfilesystem.h]
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2022-10-29 Removed wrong inheritance of SCDP and SCBR from Disk class (#948)
    * Fixed TODOs, updated SCBR and SCDP
    * Introduced ByteWriter interface
    * Use accessors instead of directly accessing length/block fields
    [gpiobus.cpp, gpiobus.h]
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2022-11-02 Code cleanup, especially casts, lambdas, data types, encapsulation (#952)
    * Lambda syntax cleanup
    * Use new-style casts
    * Use std::none_of when saving the cache
    * Use to_integer instead of casts
    * Use accessors for getting CDB data
    * Made ctrl_t private
    * Improved encapsulation
    * Replaced pointers by references
    * Removed all remaining occurrences of DWORD and BYTE, making os.h obsolete
    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
    [cfilesystem.h]
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2022-11-02 Use lambdas for dispatcher, code cleanup, test updates (#958)
    * Using lambdas instead of member function pointers simplifies the command dispatching and reduces the code volume
    * Fix for issue #956
    * Resolved SonarQube issues
    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
    [gpiobus.cpp, gpiobus.h]
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2022-11-09 rasdump and monitor updates, made rasdump work, improved bus abstraction (#973)
    * Moved rasdump and monitor to sub-folders, cleaned up code
    * Fixes rasdump issues and added additional features like device type check, LUN support and configurable buffer size
    [gpiobus.cpp, gpiobus.h, gpiobus_factory.cpp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]
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2023-03-28 Fixed a potential issue with the unit test order (reserved file cleanup was missing) (#1137)
    * Fixed a potential issue with the unit test order
    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
    [gpiobus_raspberry.cpp]
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2023-06-24 Clarify docs and error strings for scsimon (#1175)
    * Better usage hints in scsimon man page
    * In error message, clarify that piscsi needs to be shut down
    [gpiobus_raspberry.cpp]
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2023-10-15 Issues 1179 and 1182 (#1232)
    * Update logging
    * Remove duplicate code
    * Update unit tests
    * Clean up includes
    * Merge ProtobufSerializer into protobuf_util namespace
    * Precompile regex
    * Add const
    * Add Split() convenience method, update log level/ID parsing
    * Move log.h to legacy folder
    * Elimininate gotos
    * Fixes for gcc 13
    * Update compiler flags
    * Update default folder handling
    * Use references instead of pointers
    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
    [cfilesystem.h]
2023-10-22 Remove non-working Banana Pi code (#1252)
    * Remove non-working Banana Pi code
    * Remove SonarQube suppressions which can be resolved by a code update
    * Update device detection
    [gpiobus.cpp, gpiobus.h, gpiobus_factory.cpp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]
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2023-11-08 Fix MESSAGE OUT handling for initiator mode (#1283) (#1284)
    * Fix MESSAGE OUT handling
    * Add assertion
    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
    [gpiobus.cpp]
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2023-11-10 Add missing time unit (#1329)
    [gpiobus.cpp]
2023-11-13 Fix BSY pin handling in initiator mode (#1312)
    * In initiator mode configure BSY as an output pin when BSY is set
    [gpiobus_raspberry.cpp]
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2023-11-14 Use standard C++ timer for long timeouts (#1327), remove unused code (#1328)
    * Replace timer in WaitSignal()
    ' Remove unused code
    * Remove unused file
    [gpiobus.cpp, gpiobus.h, gpiobus_raspberry.cpp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]
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2026-08-15 scsiloop: gate hardware diagnostics by platform
    Replace getopt() and usleep() dependencies with portable C++ parsing and sleeps. Refuse to execute the GPIO loopback diagnostic off Linux/Raspberry Pi hardware, and omit the hardware-only target from non-Linux Meson builds.
    [scsiloop_gpio.cpp]
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2026-08-31 replace compile-time board types with runtime profiles
    Move GPIO mappings into a single module and select a board profile at process startup instead of at compile time: Build every GPIO-facing utility for every supported profile. At the same time, we remove support for the historical AIBOM board type since it's the only one using positive logic, the other three variants share the same electrical behavior.
    Run piscsi, scsimon, scsiloop, scsidump, or sasidump with -C=STANDARD, FULLSPEC, or GAMERNIUM. FULLSPEC remains the default. To select a profile for the systemd service, set PISCSI_CONNECTION_TYPE and restart the service.
    [gpiobus.h, gpiobus_raspberry.cpp, gpiobus_raspberry.h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]
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2026-09-06 abort timed-out SCSI data handshakes
    Limit IRQ-masked REQ/ACK waits to 100 ms and reset the controller and bus when a data transfer is incomplete. Do not attempt status or message recovery after the initiator stops acknowledging, preventing repeated multi-second real-time busy waits from starving the Pi.
    Add send and receive regression tests for partial handshakes.
    [gpiobus.cpp]

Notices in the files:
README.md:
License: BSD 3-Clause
